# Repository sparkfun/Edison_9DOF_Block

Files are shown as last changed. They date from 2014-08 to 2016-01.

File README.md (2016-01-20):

SparkFun Edison 9 Degrees of Freedom
=====================

SparkFun Edison 9 Degrees of Freedom

[*SparkFun Edison 9 Degrees of Freedom (DEV-13033)*](https://www.sparkfun.com/products/13033)

The 9DOF board for the Edison uses the STMicro LSM9DS0 9 Degrees of Freedom IMU for full-range motion sensing. This chip combines a 3-axis accelerometer, a 3-axis gyroscope, and a 3-axis magnetometer. By default, the IMU is connected to the Edison through the I2C bus but can be configured to use the SPI bus.

Repository Contents
-------------------
 
* **/Hardware** - Eagle design files (.brd, .sch)
* **/Production** - Production panel files (.brd)

Documentation
--------------
* **[Hookup Guide](https://learn.sparkfun.com/tutorials/sparkfun-blocks-for-intel-edison---9-degrees-of-freedom-block-)** - Basic hookup guide for the Edison 9DOF.
* **[SparkFun Fritzing repo](https://github.com/sparkfun/Fritzing_Parts)** - Fritzing diagrams for SparkFun products.
* **[SparkFun 3D Model repo](https://github.com/sparkfun/3D_Models)** - 3D models of SparkFun products. 
* **[SparkFun Graphical Datasheets](https://github.com/sparkfun/Graphical_Datasheets)** -Graphical Datasheets for various SparkFun products.

License Information
-------------------

This product is _**open source**_! 

Please review the LICENSE.md file for license information. 

If you have any questions or concerns on licensing, please contact techsupport@sparkfun.com.

Distributed as-is; no warranty is given.

- Your friends at SparkFun.

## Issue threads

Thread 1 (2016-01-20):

Are the SDA and SCL pins exposed anywhere?

mikekberg, 2016-01-20:
I'm trying to debug some communications issues with this block. Is there anywhere I can get a probe onto the SDA or SCL pins for this board?

ShawnHymel, 2016-01-20:
SDA and SCL are the pads labeled "SDA" and "SCL" on the DATA and CLOCK 3-way solder jumpers. No real pins, but you can tack a couple of wires to the pads to connect to some probes.

Closed 2016-01-20.

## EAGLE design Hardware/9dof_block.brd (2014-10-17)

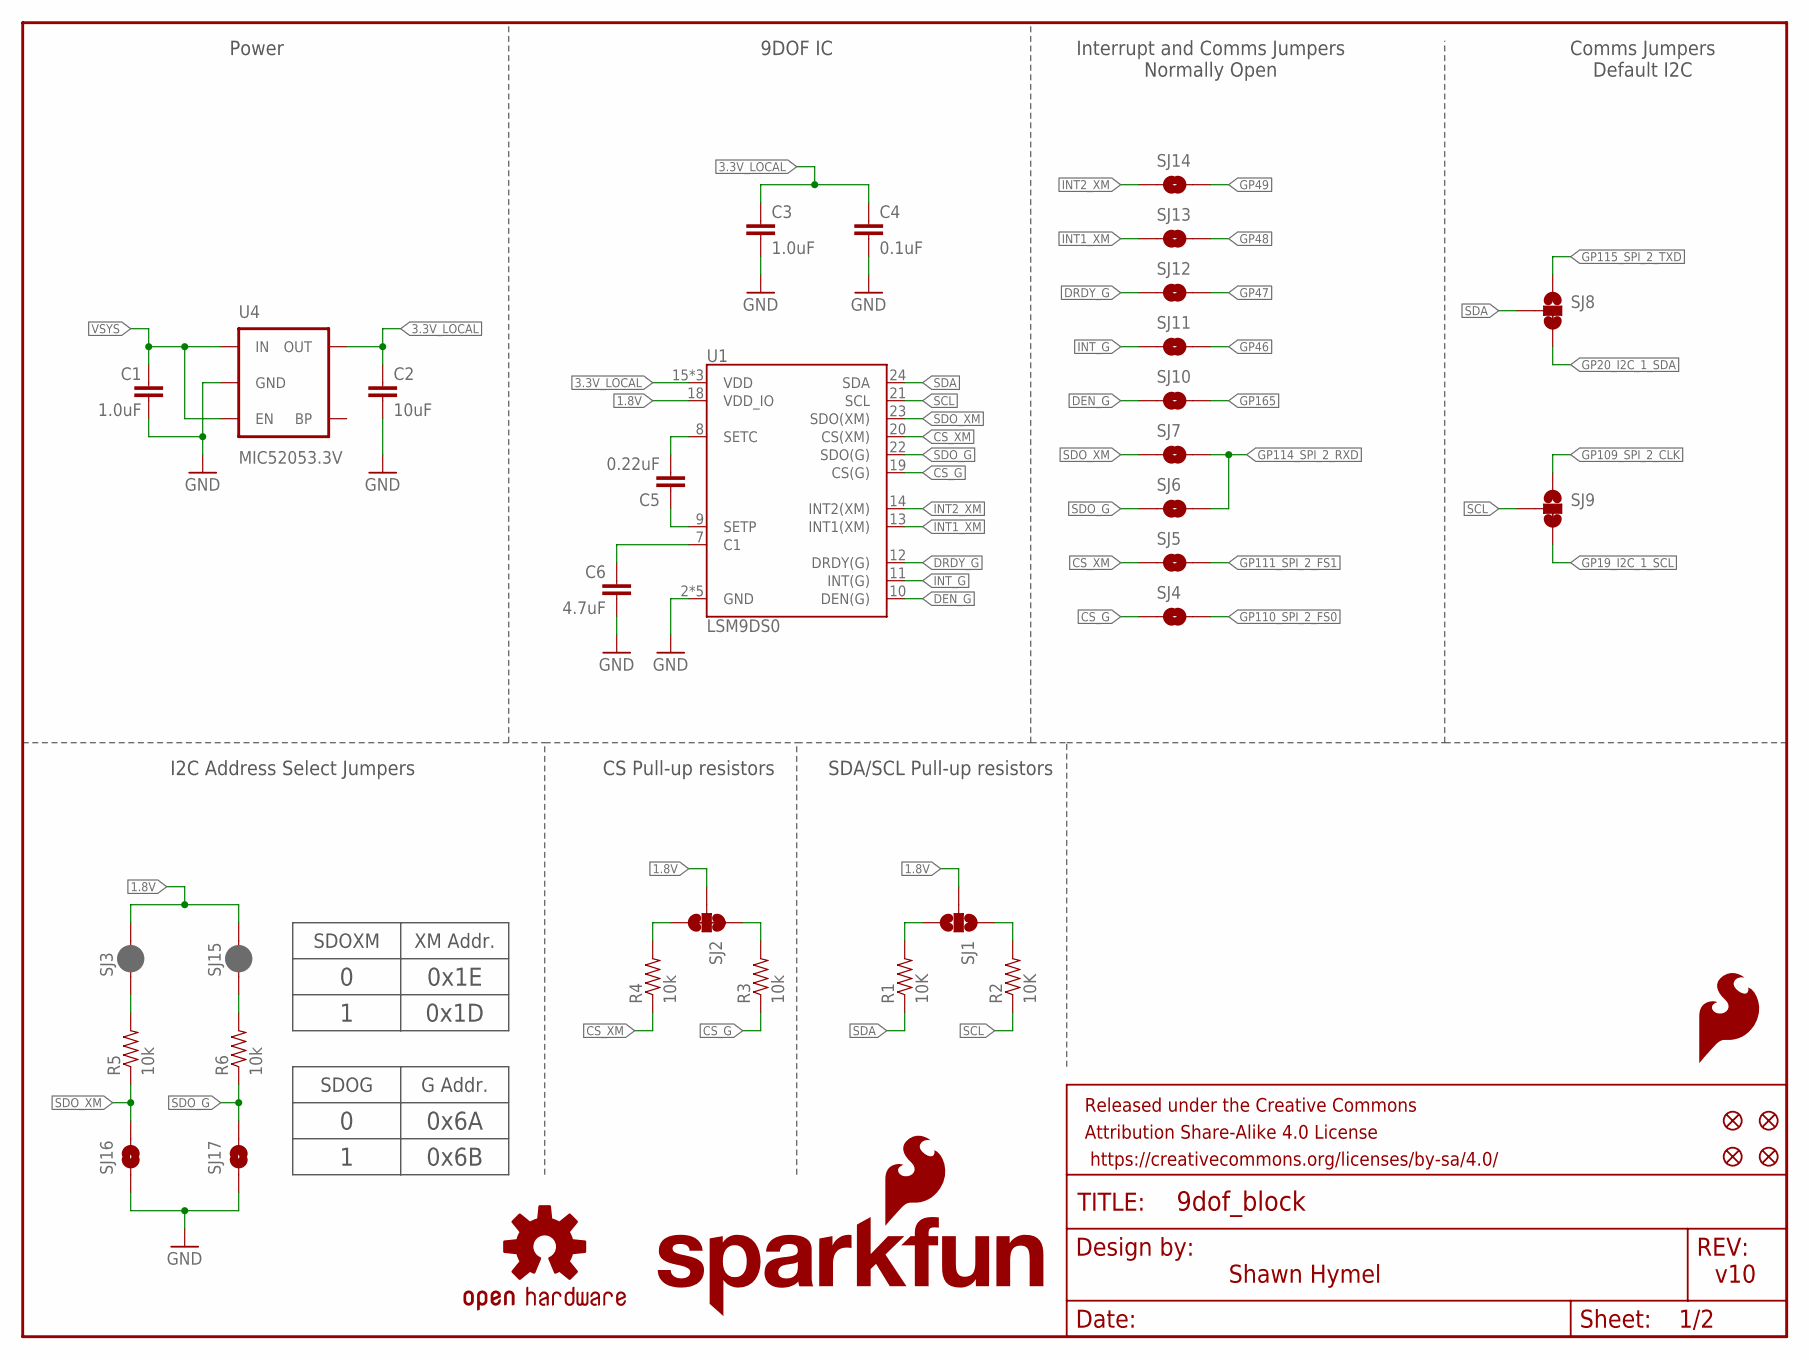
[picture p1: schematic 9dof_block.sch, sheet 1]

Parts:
C1, C3: 1.0uF; 0603-CAP
C2: 10uF; 0805
C4: 0.1uF; 0603-CAP
C5: 0.22uF; 0603-CAP
C6: 4.7uF; 0603-CAP
FID1, FID2, FID3, FID4: FIDUCIAL1X2; FIDUCIAL-1X2
FRAME1: FRAME-LETTER; CREATIVE_COMMONS
LOGO1: SFE_LOGO_FLAME.2_INCH; SFE_LOGO_FLAME_.2
LOGO2: OSHW-LOGOS; OSHW-LOGO-S
LOGO3: SFE_LOGO_NAME_FLAME.1_INCH; SFE_LOGO_NAME_FLAME_.1
R1, R2: 10K; 0603-RES
R3, R4, R5, R6: 10k; 0603-RES
SJ1: JUMPER-PAD-3-NOYES_SILK; PAD-JUMPER-3-NO_YES_SILK
SJ2: JUMPER-PAD-3-NC_BY_TRACE; PAD-JUMPER-3-3OF3_NC_BY_TRACE_YES_SILK_FULL_BOX
SJ3, SJ15: JUMPER-PAD-2-NC_BY_PASTE; PAD-JUMPER-2-NC_BY_PASTE_YES_SILK
SJ4, SJ5, SJ6, SJ7, SJ10, SJ11, SJ12, SJ13, SJ14, SJ16, SJ17: JUMPER-PAD-2-NOYES_SILK; PAD-JUMPER-2-NO_YES_SILK
SJ8, SJ9: JUMPER-PAD-3-2OF3_NC_BY_TRACE_SMALL; PAD-JUMPER-3-2OF3_NC_BY_TRACE_YES_SILK_FULL_BOX
U1: LSM9DS0; LGA-24
U4: MIC52053.3V; SOT23-5

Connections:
1.8V: SJ1.2, SJ2.2, SJ3.2, SJ15.2, U1.18 (VDD_IO); also elsewhere on the board
3.3V_LOCAL: C2.1, C3.1, C4.1, U1.15 (VDD), U1.16 (VDD), U1.17 (VDD), U4.5 (OUT)
CS_G: R3.1, SJ4.1, U1.19 (CS(G))
CS_XM: R4.1, SJ5.1, U1.20 (CS(XM))
DEN_G: SJ10.1, U1.10 (DEN(G))
DRDY_G: SJ12.1, U1.12 (DRDY(G))
GND: C1.2, C2.2, C3.2, C4.2, C6.2, SJ16.1, SJ17.1, U1.2 (GND), U1.3 (GND), U1.4 (GND), U1.5 (GND), U1.6 (GND), U4.2 (GND); also elsewhere on the board
GP19_I2C_1_SCL: SJ9.3; also elsewhere on the board
GP20_I2C_1_SDA: SJ8.3; also elsewhere on the board
GP46: SJ11.2; also elsewhere on the board
GP47: SJ12.2; also elsewhere on the board
GP48: SJ13.2; also elsewhere on the board
GP49: SJ14.2; also elsewhere on the board
GP109_SPI_2_CLK: SJ9.1; also elsewhere on the board
GP110_SPI_2_FS0: SJ4.2; also elsewhere on the board
GP111_SPI_2_FS1: SJ5.2; also elsewhere on the board
GP114_SPI_2_RXD: SJ6.2, SJ7.2; also elsewhere on the board
GP115_SPI_2_TXD: SJ8.1; also elsewhere on the board
GP165: SJ10.2; also elsewhere on the board
INT1_XM: SJ13.1, U1.13 (INT1(XM))
INT2_XM: SJ14.1, U1.14 (INT2(XM))
INT_G: SJ11.1, U1.11 (INT(G))
unnamed: C5.1, U1.9 (SETP)
unnamed: C5.2, U1.8 (SETC)
unnamed: C6.1, U1.7 (C1)
unnamed: R3.2, SJ2.1
unnamed: R4.2, SJ2.3
unnamed: R1.2, SJ1.3
unnamed: R2.2, SJ1.1
unnamed: R5.2, SJ3.1
unnamed: R6.2, SJ15.1
SCL: R2.1, SJ9.2, U1.21 (SCL)
SDA: R1.1, SJ8.2, U1.24 (SDA)
SDO_G: R6.1, SJ6.1, SJ17.2, U1.22 (SDO(G))
SDO_XM: R5.1, SJ7.1, SJ16.2, U1.23 (SDO(XM))
VSYS: C1.1, U4.1 (IN), U4.3 (EN); also elsewhere on the board

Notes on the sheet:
I2C Address Select Jumpers
SDA/SCL Pull-up resistors
9DOF IC
Interrupt and Comms Jumpers Normally Open
Comms Jumpers Default I2C
Power
CS Pull-up resistors
SDOXM
XM Addr.
0x1E
0x1D
SDOG
G Addr.
0x6A
0x6B
v10
Shawn Hymel

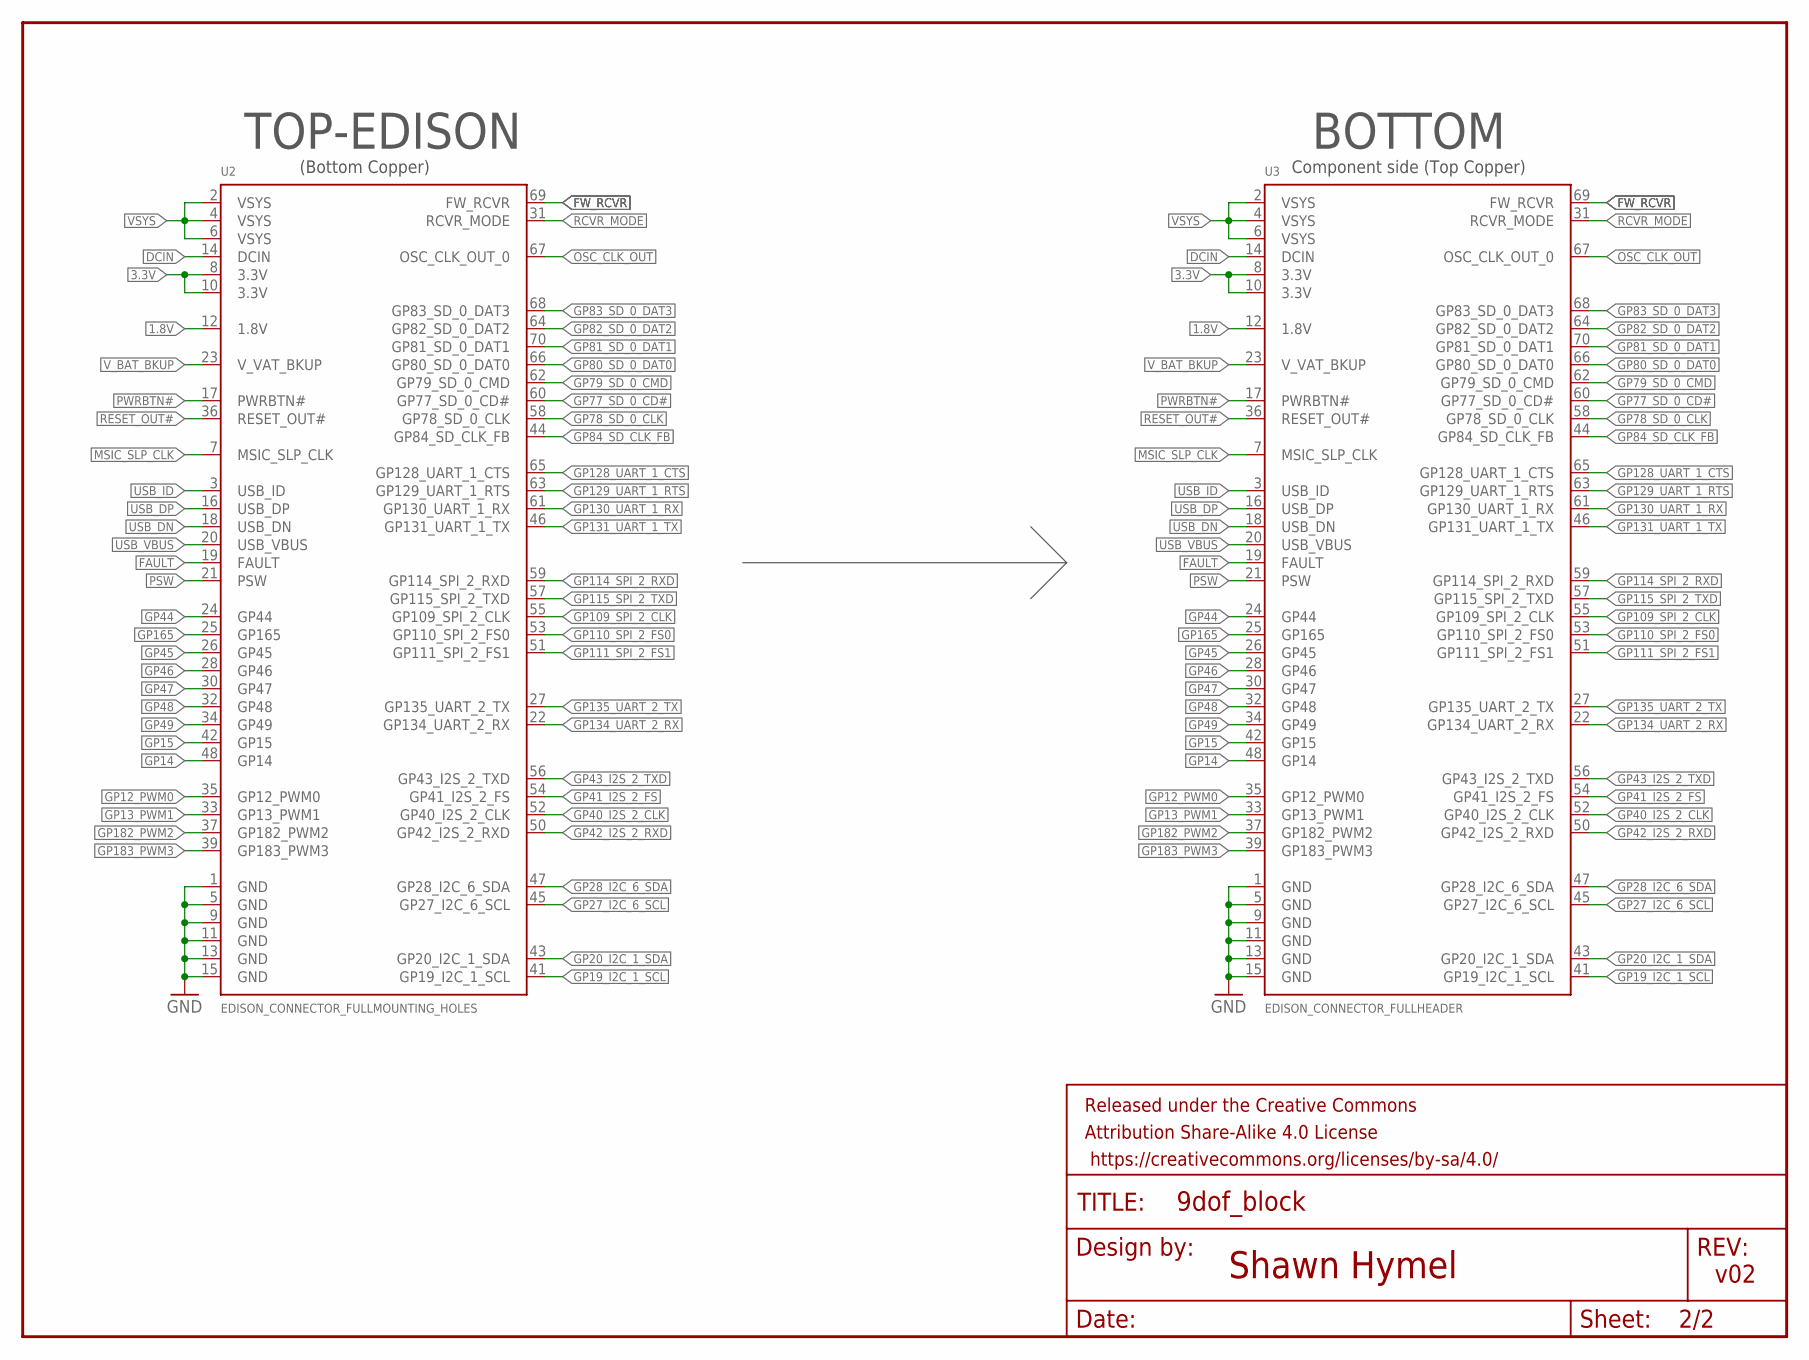
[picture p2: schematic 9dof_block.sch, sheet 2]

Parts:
FRAME2: FRAME-LETTER; CREATIVE_COMMONS
U2: EDISON_CONNECTOR_FULLMOUNTING_HOLES; EDISON_DAUGHTER
U3: EDISON_CONNECTOR_FULLHEADER; DF40C-70DP-0.4(51)

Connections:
1.8V: U2.12 (1.8V), U3.12 (1.8V); also elsewhere on the board
3.3V: U2.8 (3.3V), U2.10 (3.3V), U3.8 (3.3V), U3.10 (3.3V)
DCIN: U2.14 (DCIN), U3.14 (DCIN)
FAULT: U2.19 (FAULT), U3.19 (FAULT)
FW_RCVR: U2.69 (FW_RCVR), U3.69 (FW_RCVR)
GND: U2.1 (GND), U2.5 (GND), U2.9 (GND), U2.11 (GND), U2.13 (GND), U2.15 (GND), U3.1 (GND), U3.5 (GND), U3.9 (GND), U3.11 (GND), U3.13 (GND), U3.15 (GND); also elsewhere on the board
GP12_PWM0: U2.35 (GP12_PWM0), U3.35 (GP12_PWM0)
GP13_PWM1: U2.33 (GP13_PWM1), U3.33 (GP13_PWM1)
GP14: U2.48 (GP14), U3.48 (GP14)
GP15: U2.42 (GP15), U3.42 (GP15)
GP19_I2C_1_SCL: U2.41 (GP19_I2C_1_SCL), U3.41 (GP19_I2C_1_SCL); also elsewhere on the board
GP20_I2C_1_SDA: U2.43 (GP20_I2C_1_SDA), U3.43 (GP20_I2C_1_SDA); also elsewhere on the board
GP27_I2C_6_SCL: U2.45 (GP27_I2C_6_SCL), U3.45 (GP27_I2C_6_SCL)
GP28_I2C_6_SDA: U2.47 (GP28_I2C_6_SDA), U3.47 (GP28_I2C_6_SDA)
GP40_I2S_2_CLK: U2.52 (GP40_I2S_2_CLK), U3.52 (GP40_I2S_2_CLK)
GP41_I2S_2_FS: U2.54 (GP41_I2S_2_FS), U3.54 (GP41_I2S_2_FS)
GP42_I2S_2_RXD: U2.50 (GP42_I2S_2_RXD), U3.50 (GP42_I2S_2_RXD)
GP43_I2S_2_TXD: U2.56 (GP43_I2S_2_TXD), U3.56 (GP43_I2S_2_TXD)
GP44: U2.24 (GP44), U3.24 (GP44)
GP45: U2.26 (GP45), U3.26 (GP45)
GP46: U2.28 (GP46), U3.28 (GP46); also elsewhere on the board
GP47: U2.30 (GP47), U3.30 (GP47); also elsewhere on the board
GP48: U2.32 (GP48), U3.32 (GP48); also elsewhere on the board
GP49: U2.34 (GP49), U3.34 (GP49); also elsewhere on the board
GP77_SD_0_CD#: U2.60 (GP77_SD_0_CD#), U3.60 (GP77_SD_0_CD#)
GP78_SD_0_CLK: U2.58 (GP78_SD_0_CLK), U3.58 (GP78_SD_0_CLK)
GP79_SD_0_CMD: U2.62 (GP79_SD_0_CMD), U3.62 (GP79_SD_0_CMD)
GP80_SD_0_DAT0: U2.66 (GP80_SD_0_DAT0), U3.66 (GP80_SD_0_DAT0)
GP81_SD_0_DAT1: U2.70 (GP81_SD_0_DAT1), U3.70 (GP81_SD_0_DAT1)
GP82_SD_0_DAT2: U2.64 (GP82_SD_0_DAT2), U3.64 (GP82_SD_0_DAT2)
GP83_SD_0_DAT3: U2.68 (GP83_SD_0_DAT3), U3.68 (GP83_SD_0_DAT3)
GP84_SD_CLK_FB: U2.44 (GP84_SD_CLK_FB), U3.44 (GP84_SD_CLK_FB)
GP109_SPI_2_CLK: U2.55 (GP109_SPI_2_CLK), U3.55 (GP109_SPI_2_CLK); also elsewhere on the board
GP110_SPI_2_FS0: U2.53 (GP110_SPI_2_FS0), U3.53 (GP110_SPI_2_FS0); also elsewhere on the board
GP111_SPI_2_FS1: U2.51 (GP111_SPI_2_FS1), U3.51 (GP111_SPI_2_FS1); also elsewhere on the board
GP114_SPI_2_RXD: U2.59 (GP114_SPI_2_RXD), U3.59 (GP114_SPI_2_RXD); also elsewhere on the board
GP115_SPI_2_TXD: U2.57 (GP115_SPI_2_TXD), U3.57 (GP115_SPI_2_TXD); also elsewhere on the board
GP128_UART_1_CTS: U2.65 (GP128_UART_1_CTS), U3.65 (GP128_UART_1_CTS)
GP129_UART_1_RTS: U2.63 (GP129_UART_1_RTS), U3.63 (GP129_UART_1_RTS)
GP130_UART_1_RX: U2.61 (GP130_UART_1_RX), U3.61 (GP130_UART_1_RX)
GP131_UART_1_TX: U2.46 (GP131_UART_1_TX), U3.46 (GP131_UART_1_TX)
GP134_UART_2_RX: U2.22 (GP134_UART_2_RX), U3.22 (GP134_UART_2_RX)
GP135_UART_2_TX: U2.27 (GP135_UART_2_TX), U3.27 (GP135_UART_2_TX)
GP165: U2.25 (GP165), U3.25 (GP165); also elsewhere on the board
GP182_PWM2: U2.37 (GP182_PWM2), U3.37 (GP182_PWM2)
GP183_PWM3: U2.39 (GP183_PWM3), U3.39 (GP183_PWM3)
MSIC_SLP_CLK: U2.7 (MSIC_SLP_CLK), U3.7 (MSIC_SLP_CLK)
OSC_CLK_OUT: U2.67 (OSC_CLK_OUT_0), U3.67 (OSC_CLK_OUT_0)
PSW: U2.21 (PSW), U3.21 (PSW)
PWRBTN#: U2.17 (PWRBTN#), U3.17 (PWRBTN#)
RCVR_MODE: U2.31 (RCVR_MODE), U3.31 (RCVR_MODE)
RESET_OUT#: U2.36 (RESET_OUT#), U3.36 (RESET_OUT#)
USB_DN: U2.18 (USB_DN), U3.18 (USB_DN)
USB_DP: U2.16 (USB_DP), U3.16 (USB_DP)
USB_ID: U2.3 (USB_ID), U3.3 (USB_ID)
USB_VBUS: U2.20 (USB_VBUS), U3.20 (USB_VBUS)
VSYS: U2.2 (VSYS), U2.4 (VSYS), U2.6 (VSYS), U3.2 (VSYS), U3.4 (VSYS), U3.6 (VSYS); also elsewhere on the board
V_BAT_BKUP: U2.23 (V_VAT_BKUP), U3.23 (V_VAT_BKUP)

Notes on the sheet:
TOP-EDISON
BOTTOM
Component side (Top Copper)
(Bottom Copper)
Shawn Hymel
v02

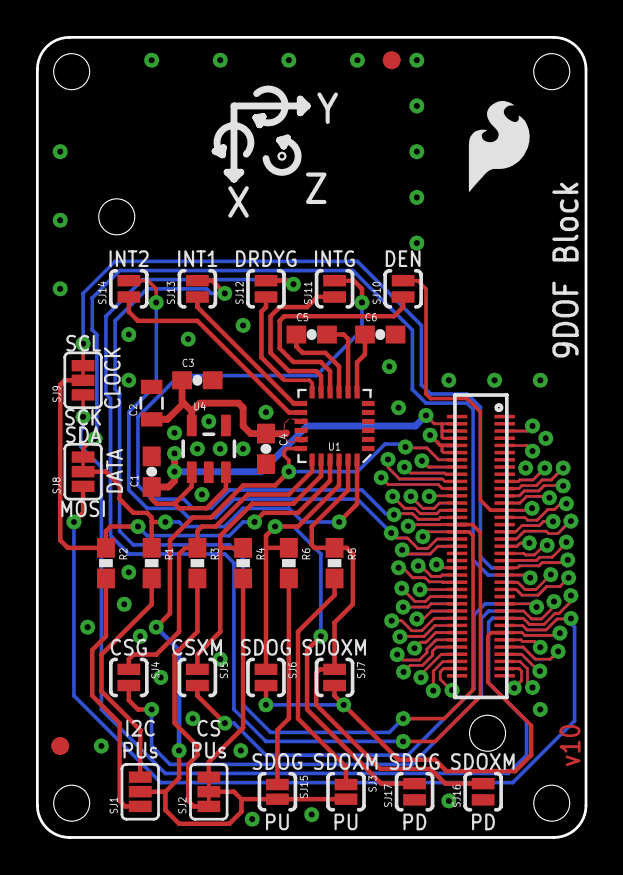
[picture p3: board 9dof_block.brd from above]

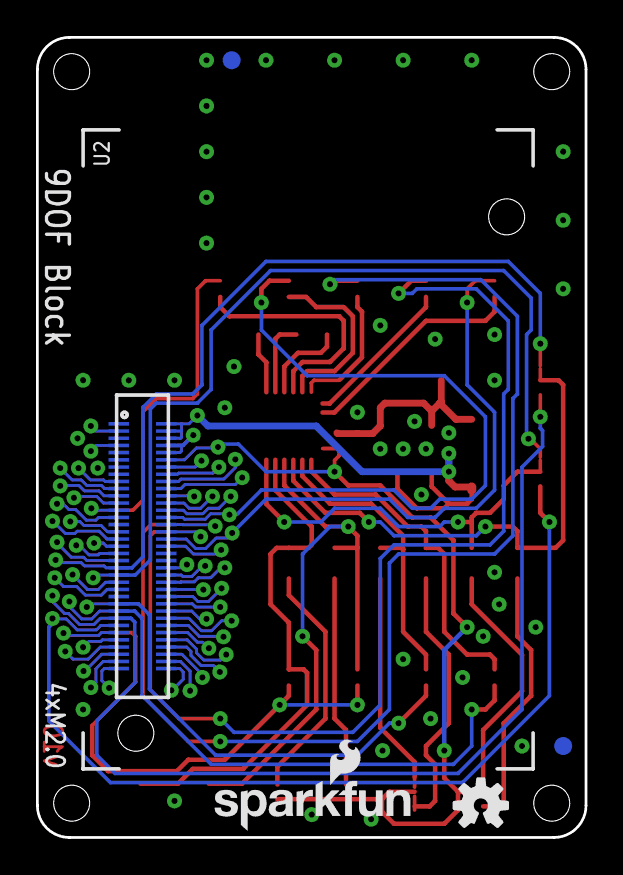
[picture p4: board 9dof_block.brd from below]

Board: 2 copper layers, 30.5 x 44.5 mm, 42 parts (6 on the bottom side), 79 nets.

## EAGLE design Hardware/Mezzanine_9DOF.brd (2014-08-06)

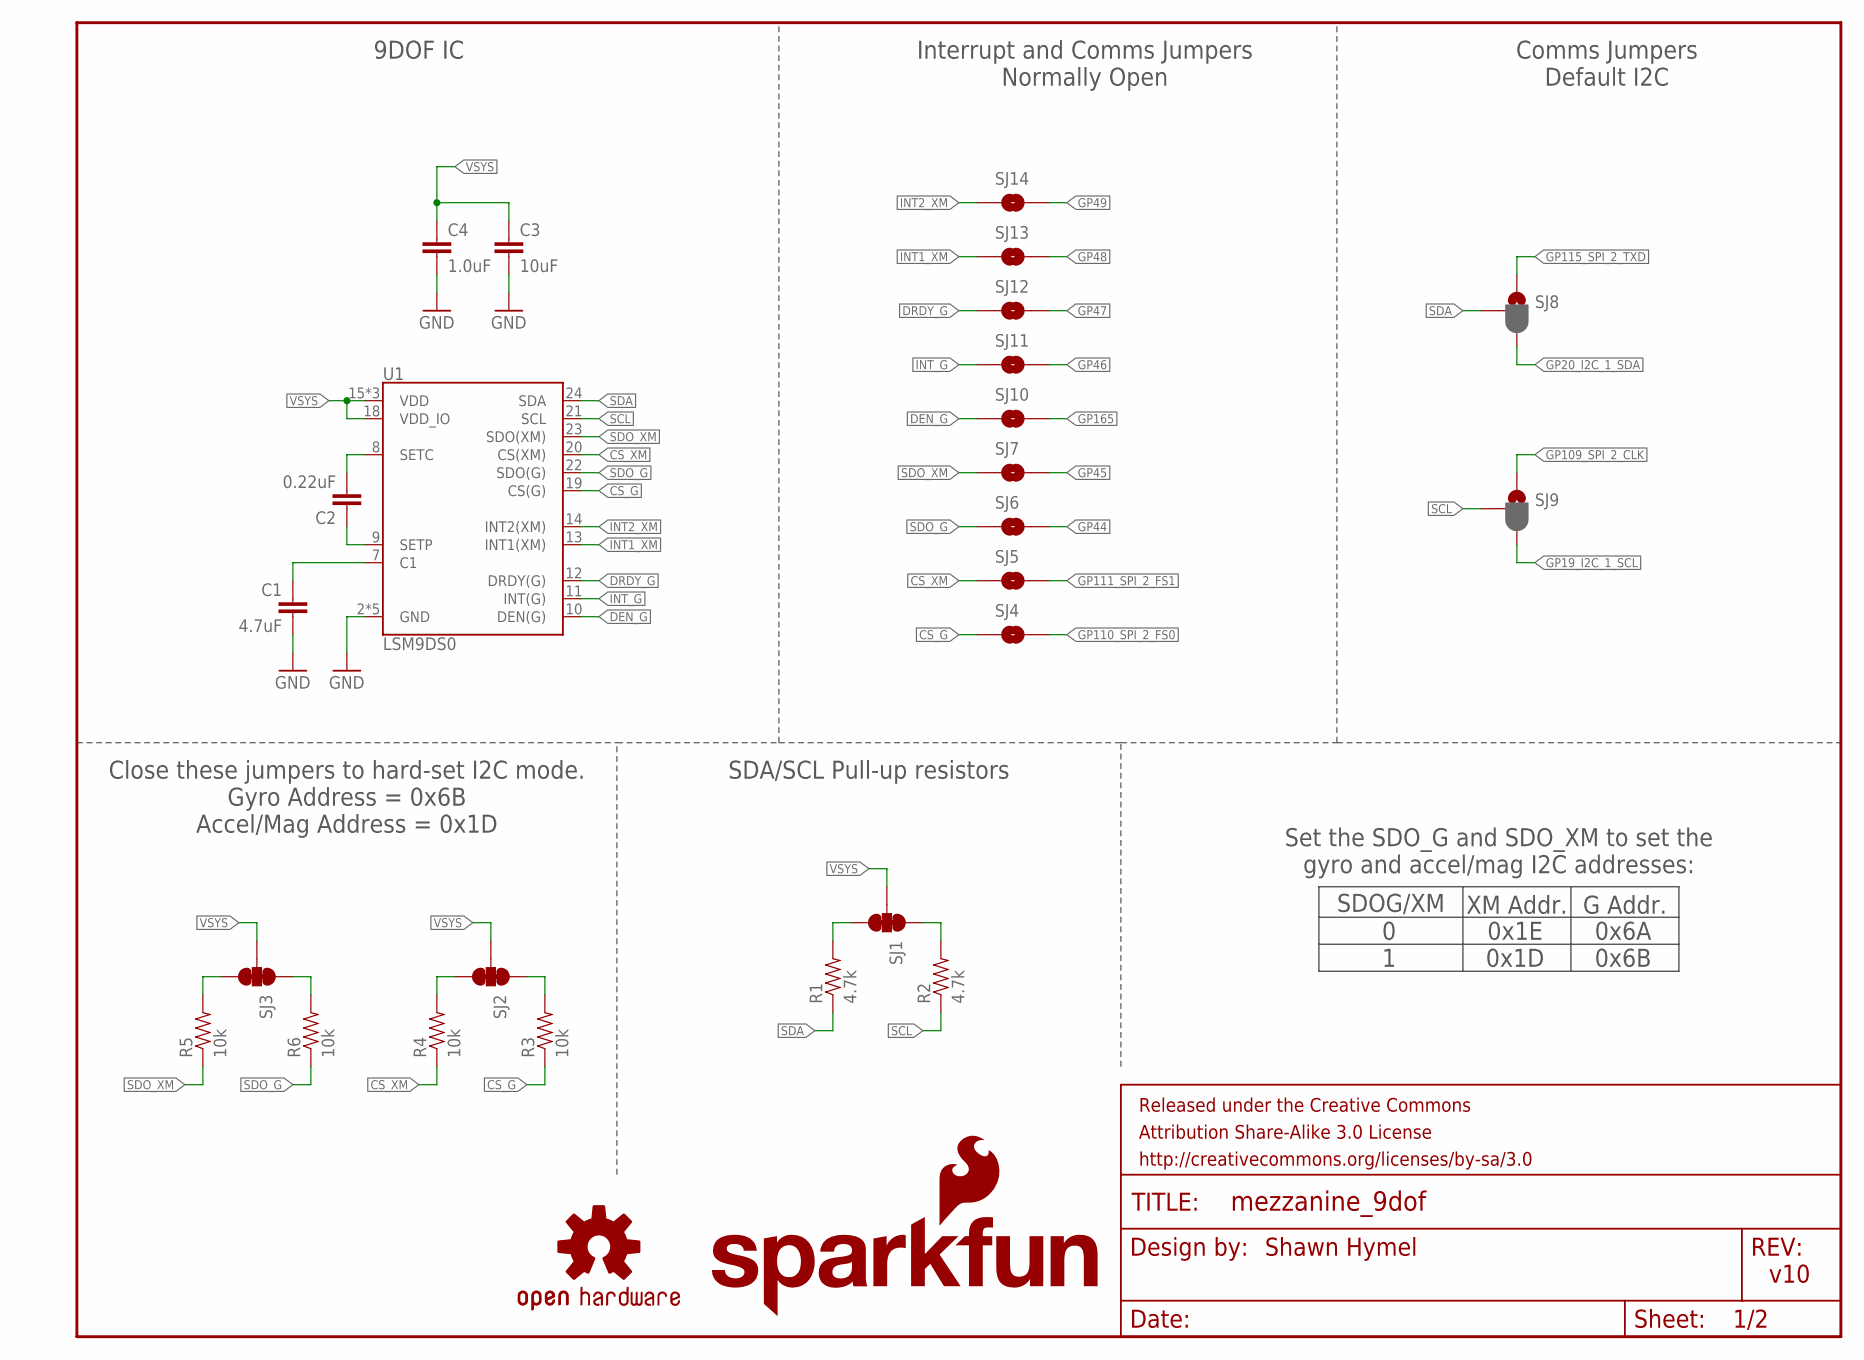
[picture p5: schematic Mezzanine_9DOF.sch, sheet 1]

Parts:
C1: 4.7uF; 0603-CAP
C2: 0.22uF; 0603-CAP
C3: 10uF; 0805
C4: 1.0uF; 0603-CAP
FRAME1: FRAME-LETTER; CREATIVE_COMMONS
LOGO2: OSHW-LOGOS; OSHW-LOGO-S
LOGO3: SFE_LOGO_NAME_FLAME.1_INCH; SFE_LOGO_NAME_FLAME_.1
R1, R2: 4.7k; 0603-RES
R3, R4, R5, R6: 10k; 0603-RES
SJ1, SJ2, SJ3: SOLDERJUMPER_2WAYS; SJ_3
SJ4, SJ5, SJ6, SJ7, SJ10, SJ11, SJ12, SJ13, SJ14: JUMPER-PAD-2-NOYES_SILK; PAD-JUMPER-2-NO_YES_SILK
SJ8, SJ9: JUMPER-PAD-3-2OF3_NC_BY_PASTE; PAD-JUMPER-3-2OF3_NC_BY_PASTE_YES_SILK_FULL_BOX
U1: LSM9DS0; LGA-24

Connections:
CS_G: R3.1, SJ4.1, U1.19 (CS(G))
CS_XM: R4.1, SJ5.1, U1.20 (CS(XM))
DEN_G: SJ10.1, U1.10 (DEN(G))
DRDY_G: SJ12.1, U1.12 (DRDY(G))
GND: C1.2, C3.2, C4.2, U1.2 (GND), U1.3 (GND), U1.4 (GND), U1.5 (GND), U1.6 (GND); also elsewhere on the board
GP19_I2C_1_SCL: SJ9.3; also elsewhere on the board
GP20_I2C_1_SDA: SJ8.3; also elsewhere on the board
GP44: SJ6.2; also elsewhere on the board
GP45: SJ7.2; also elsewhere on the board
GP46: SJ11.2; also elsewhere on the board
GP47: SJ12.2; also elsewhere on the board
GP48: SJ13.2; also elsewhere on the board
GP49: SJ14.2; also elsewhere on the board
GP109_SPI_2_CLK: SJ9.1; also elsewhere on the board
GP110_SPI_2_FS0: SJ4.2; also elsewhere on the board
GP111_SPI_2_FS1: SJ5.2; also elsewhere on the board
GP115_SPI_2_TXD: SJ8.1; also elsewhere on the board
GP165: SJ10.2; also elsewhere on the board
INT1_XM: SJ13.1, U1.13 (INT1(XM))
INT2_XM: SJ14.1, U1.14 (INT2(XM))
INT_G: SJ11.1, U1.11 (INT(G))
unnamed: C2.1, U1.9 (SETP)
unnamed: C2.2, U1.8 (SETC)
unnamed: C1.1, U1.7 (C1)
unnamed: R3.2, SJ2.1
unnamed: R4.2, SJ2.3
unnamed: R1.2, SJ1.3
unnamed: R2.2, SJ1.1
unnamed: R5.2, SJ3.3
unnamed: R6.2, SJ3.1
SCL: R2.1, SJ9.2, U1.21 (SCL)
SDA: R1.1, SJ8.2, U1.24 (SDA)
SDO_G: R6.1, SJ6.1, U1.22 (SDO(G))
SDO_XM: R5.1, SJ7.1, U1.23 (SDO(XM))
VSYS: C3.1, C4.1, SJ1.2, SJ2.2, SJ3.2, U1.15 (VDD), U1.16 (VDD), U1.17 (VDD), U1.18 (VDD_IO); also elsewhere on the board

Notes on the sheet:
Close these jumpers to hard-set I2C mode. Gyro Address = 0x6B Accel/Mag Address = 0x1D
SDA/SCL Pull-up resistors
SDOG/XM
0x1E 0x1D
XM Addr.
0 1
G Addr.
0x6A 0x6B
Set the SDO_G and SDO_XM to set the gyro and accel/mag I2C addresses:
Shawn Hymel
v10
9DOF IC
Interrupt and Comms Jumpers Normally Open
Comms Jumpers Default I2C

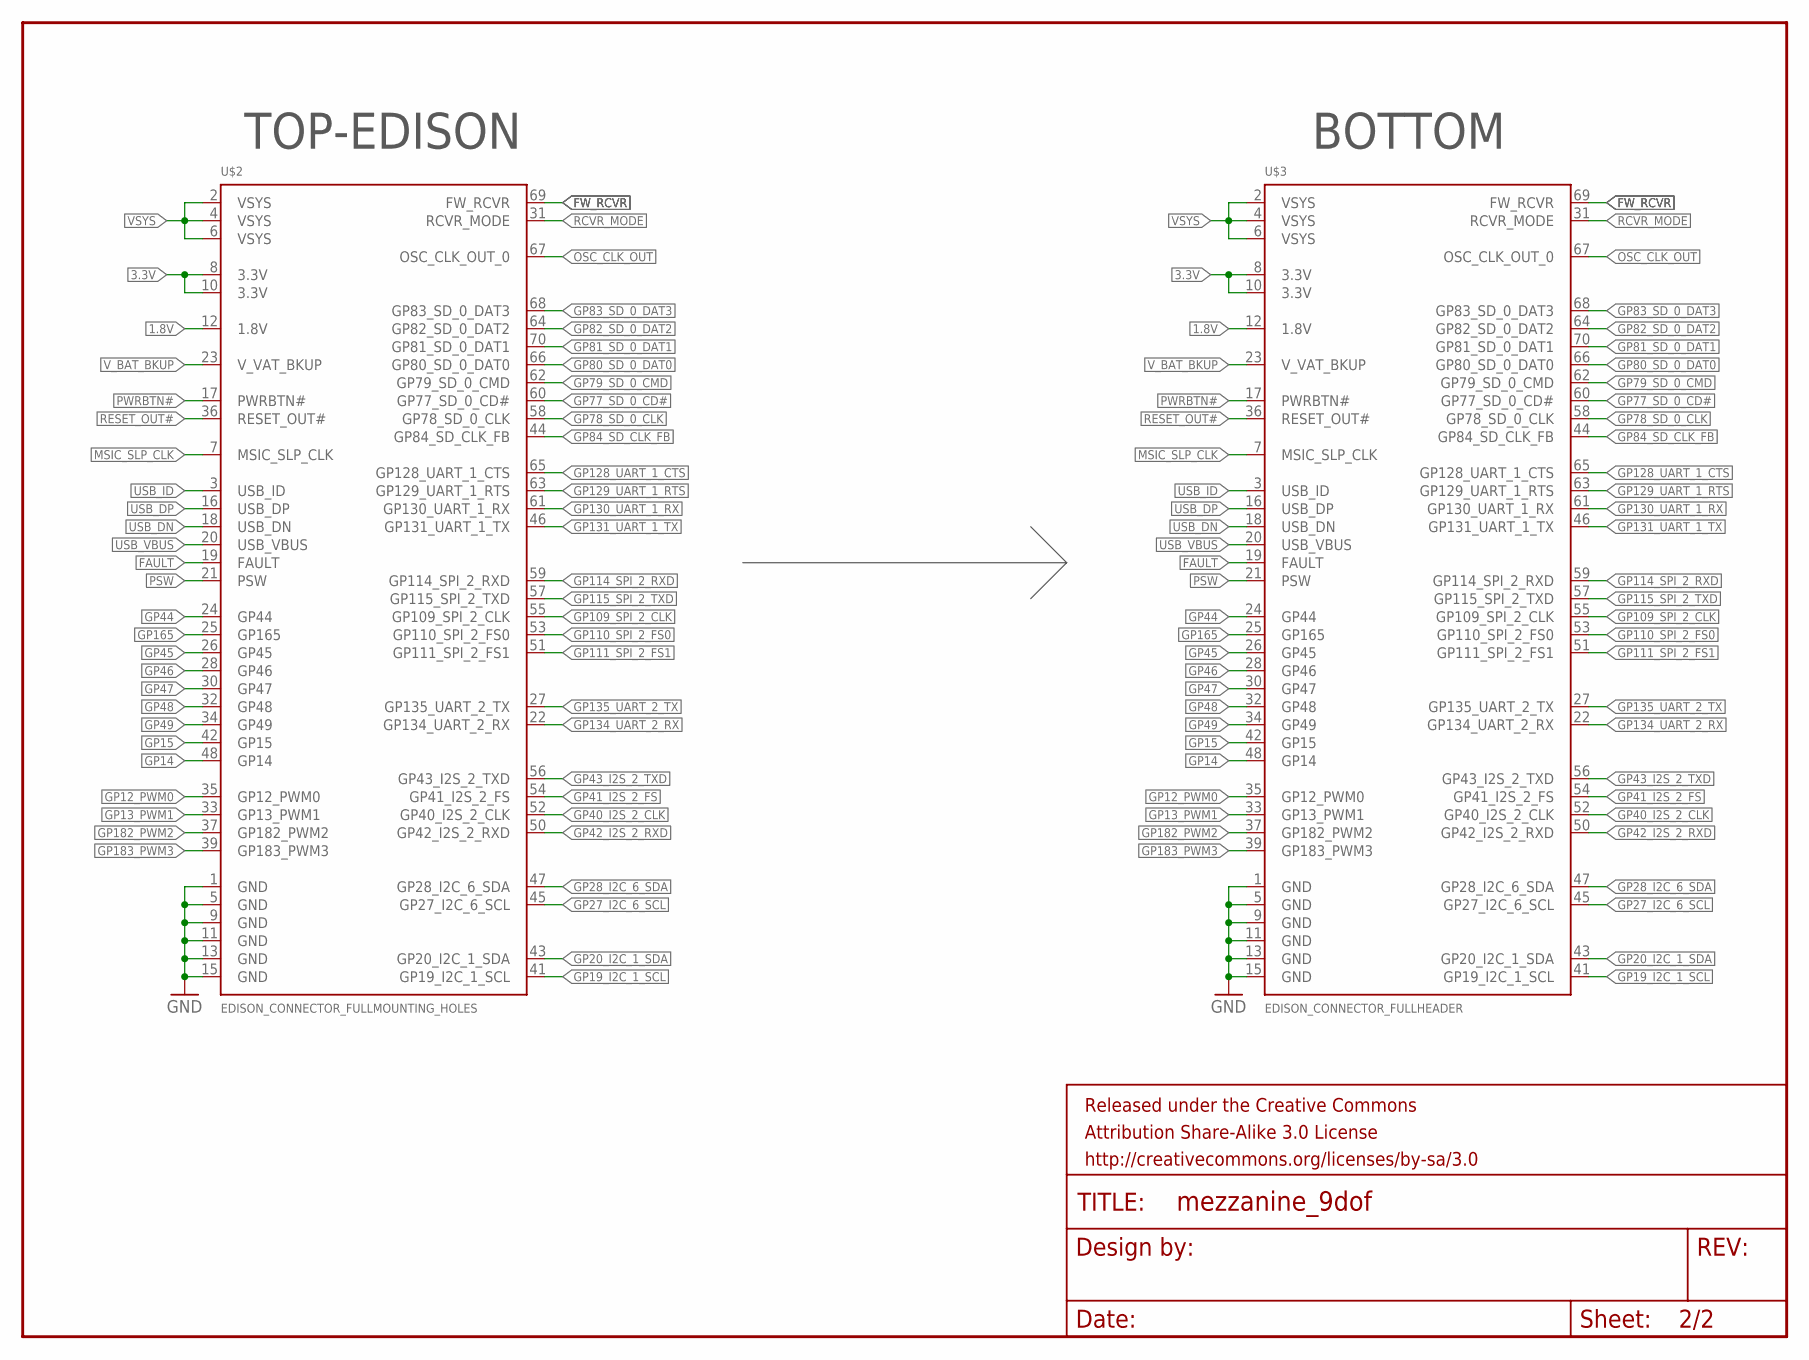
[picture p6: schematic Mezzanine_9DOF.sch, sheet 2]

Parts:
FRAME2: FRAME-LETTER; CREATIVE_COMMONS
U$2: EDISON_CONNECTOR_FULLMOUNTING_HOLES; EDISON_DAUGHTER
U$3: EDISON_CONNECTOR_FULLHEADER; DF40C-70DP-0.4(51)

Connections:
1.8V: U$2.12 (1.8V), U$3.12 (1.8V)
3.3V: U$2.8 (3.3V), U$2.10 (3.3V), U$3.8 (3.3V), U$3.10 (3.3V)
FAULT: U$2.19 (FAULT), U$3.19 (FAULT)
FW_RCVR: U$2.69 (FW_RCVR), U$3.69 (FW_RCVR)
GND: U$2.1 (GND), U$2.5 (GND), U$2.9 (GND), U$2.11 (GND), U$2.13 (GND), U$2.15 (GND), U$3.1 (GND), U$3.5 (GND), U$3.9 (GND), U$3.11 (GND), U$3.13 (GND), U$3.15 (GND); also elsewhere on the board
GP12_PWM0: U$2.35 (GP12_PWM0), U$3.35 (GP12_PWM0)
GP13_PWM1: U$2.33 (GP13_PWM1), U$3.33 (GP13_PWM1)
GP14: U$2.48 (GP14), U$3.48 (GP14)
GP15: U$2.42 (GP15), U$3.42 (GP15)
GP19_I2C_1_SCL: U$2.41 (GP19_I2C_1_SCL), U$3.41 (GP19_I2C_1_SCL); also elsewhere on the board
GP20_I2C_1_SDA: U$2.43 (GP20_I2C_1_SDA), U$3.43 (GP20_I2C_1_SDA); also elsewhere on the board
GP27_I2C_6_SCL: U$2.45 (GP27_I2C_6_SCL), U$3.45 (GP27_I2C_6_SCL)
GP28_I2C_6_SDA: U$2.47 (GP28_I2C_6_SDA), U$3.47 (GP28_I2C_6_SDA)
GP40_I2S_2_CLK: U$2.52 (GP40_I2S_2_CLK), U$3.52 (GP40_I2S_2_CLK)
GP41_I2S_2_FS: U$2.54 (GP41_I2S_2_FS), U$3.54 (GP41_I2S_2_FS)
GP42_I2S_2_RXD: U$2.50 (GP42_I2S_2_RXD), U$3.50 (GP42_I2S_2_RXD)
GP43_I2S_2_TXD: U$2.56 (GP43_I2S_2_TXD), U$3.56 (GP43_I2S_2_TXD)
GP44: U$2.24 (GP44), U$3.24 (GP44); also elsewhere on the board
GP45: U$2.26 (GP45), U$3.26 (GP45); also elsewhere on the board
GP46: U$2.28 (GP46), U$3.28 (GP46); also elsewhere on the board
GP47: U$2.30 (GP47), U$3.30 (GP47); also elsewhere on the board
GP48: U$2.32 (GP48), U$3.32 (GP48); also elsewhere on the board
GP49: U$2.34 (GP49), U$3.34 (GP49); also elsewhere on the board
GP77_SD_0_CD#: U$2.60 (GP77_SD_0_CD#), U$3.60 (GP77_SD_0_CD#)
GP78_SD_0_CLK: U$2.58 (GP78_SD_0_CLK), U$3.58 (GP78_SD_0_CLK)
GP79_SD_0_CMD: U$2.62 (GP79_SD_0_CMD), U$3.62 (GP79_SD_0_CMD)
GP80_SD_0_DAT0: U$2.66 (GP80_SD_0_DAT0), U$3.66 (GP80_SD_0_DAT0)
GP81_SD_0_DAT1: U$2.70 (GP81_SD_0_DAT1), U$3.70 (GP81_SD_0_DAT1)
GP82_SD_0_DAT2: U$2.64 (GP82_SD_0_DAT2), U$3.64 (GP82_SD_0_DAT2)
GP83_SD_0_DAT3: U$2.68 (GP83_SD_0_DAT3), U$3.68 (GP83_SD_0_DAT3)
GP84_SD_CLK_FB: U$2.44 (GP84_SD_CLK_FB), U$3.44 (GP84_SD_CLK_FB)
GP109_SPI_2_CLK: U$2.55 (GP109_SPI_2_CLK), U$3.55 (GP109_SPI_2_CLK); also elsewhere on the board
GP110_SPI_2_FS0: U$2.53 (GP110_SPI_2_FS0), U$3.53 (GP110_SPI_2_FS0); also elsewhere on the board
GP111_SPI_2_FS1: U$2.51 (GP111_SPI_2_FS1), U$3.51 (GP111_SPI_2_FS1); also elsewhere on the board
GP114_SPI_2_RXD: U$2.59 (GP114_SPI_2_RXD), U$3.59 (GP114_SPI_2_RXD)
GP115_SPI_2_TXD: U$2.57 (GP115_SPI_2_TXD), U$3.57 (GP115_SPI_2_TXD); also elsewhere on the board
GP128_UART_1_CTS: U$2.65 (GP128_UART_1_CTS), U$3.65 (GP128_UART_1_CTS)
GP129_UART_1_RTS: U$2.63 (GP129_UART_1_RTS), U$3.63 (GP129_UART_1_RTS)
GP130_UART_1_RX: U$2.61 (GP130_UART_1_RX), U$3.61 (GP130_UART_1_RX)
GP131_UART_1_TX: U$2.46 (GP131_UART_1_TX), U$3.46 (GP131_UART_1_TX)
GP134_UART_2_RX: U$2.22 (GP134_UART_2_RX), U$3.22 (GP134_UART_2_RX)
GP135_UART_2_TX: U$2.27 (GP135_UART_2_TX), U$3.27 (GP135_UART_2_TX)
GP165: U$2.25 (GP165), U$3.25 (GP165); also elsewhere on the board
GP182_PWM2: U$2.37 (GP182_PWM2), U$3.37 (GP182_PWM2)
GP183_PWM3: U$2.39 (GP183_PWM3), U$3.39 (GP183_PWM3)
MSIC_SLP_CLK: U$2.7 (MSIC_SLP_CLK), U$3.7 (MSIC_SLP_CLK)
OSC_CLK_OUT: U$2.67 (OSC_CLK_OUT_0), U$3.67 (OSC_CLK_OUT_0)
PSW: U$2.21 (PSW), U$3.21 (PSW)
PWRBTN#: U$2.17 (PWRBTN#), U$3.17 (PWRBTN#)
RCVR_MODE: U$2.31 (RCVR_MODE), U$3.31 (RCVR_MODE)
RESET_OUT#: U$2.36 (RESET_OUT#), U$3.36 (RESET_OUT#)
USB_DN: U$2.18 (USB_DN), U$3.18 (USB_DN)
USB_DP: U$2.16 (USB_DP), U$3.16 (USB_DP)
USB_ID: U$2.3 (USB_ID), U$3.3 (USB_ID)
USB_VBUS: U$2.20 (USB_VBUS), U$3.20 (USB_VBUS)
VSYS: U$2.2 (VSYS), U$2.4 (VSYS), U$2.6 (VSYS), U$3.2 (VSYS), U$3.4 (VSYS), U$3.6 (VSYS); also elsewhere on the board
V_BAT_BKUP: U$2.23 (V_VAT_BKUP), U$3.23 (V_VAT_BKUP)

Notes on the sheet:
TOP-EDISON
BOTTOM

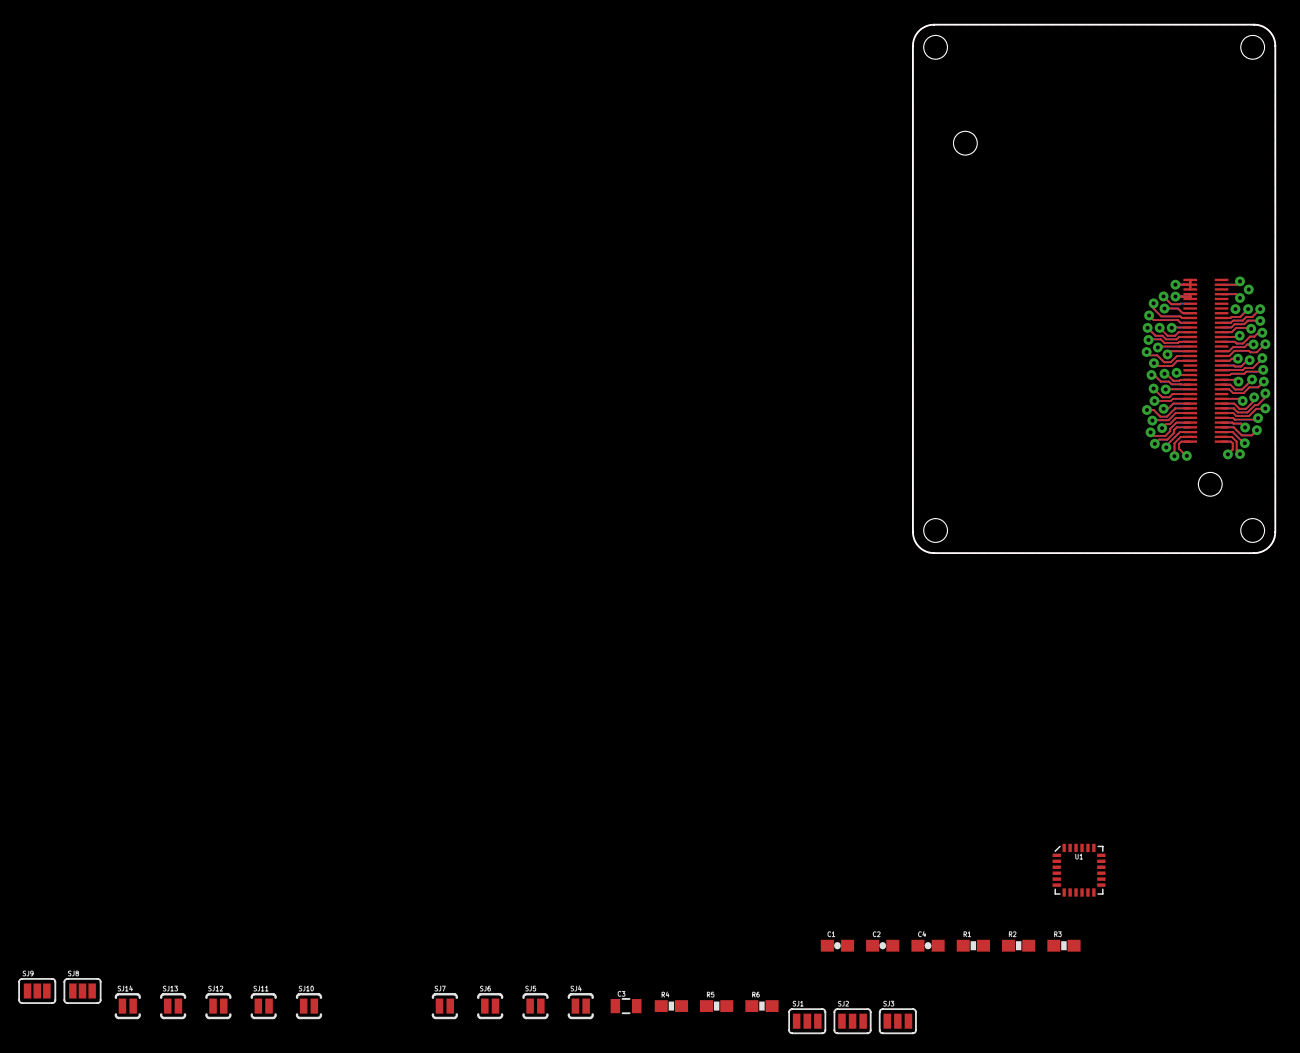
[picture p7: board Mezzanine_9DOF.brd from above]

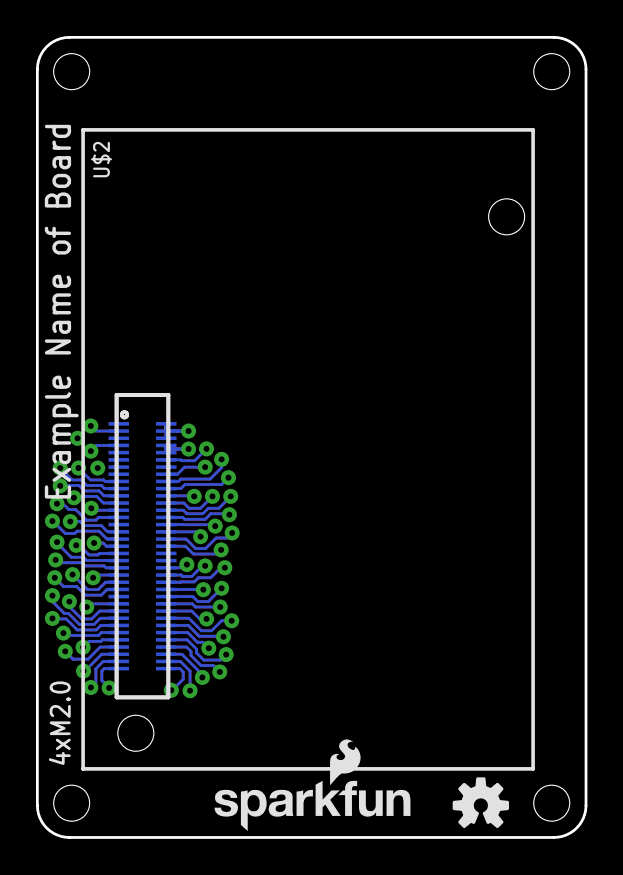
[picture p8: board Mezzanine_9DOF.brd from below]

Board: 2 copper layers, 30.5 x 44.5 mm, 31 parts (4 on the bottom side), 77 nets.

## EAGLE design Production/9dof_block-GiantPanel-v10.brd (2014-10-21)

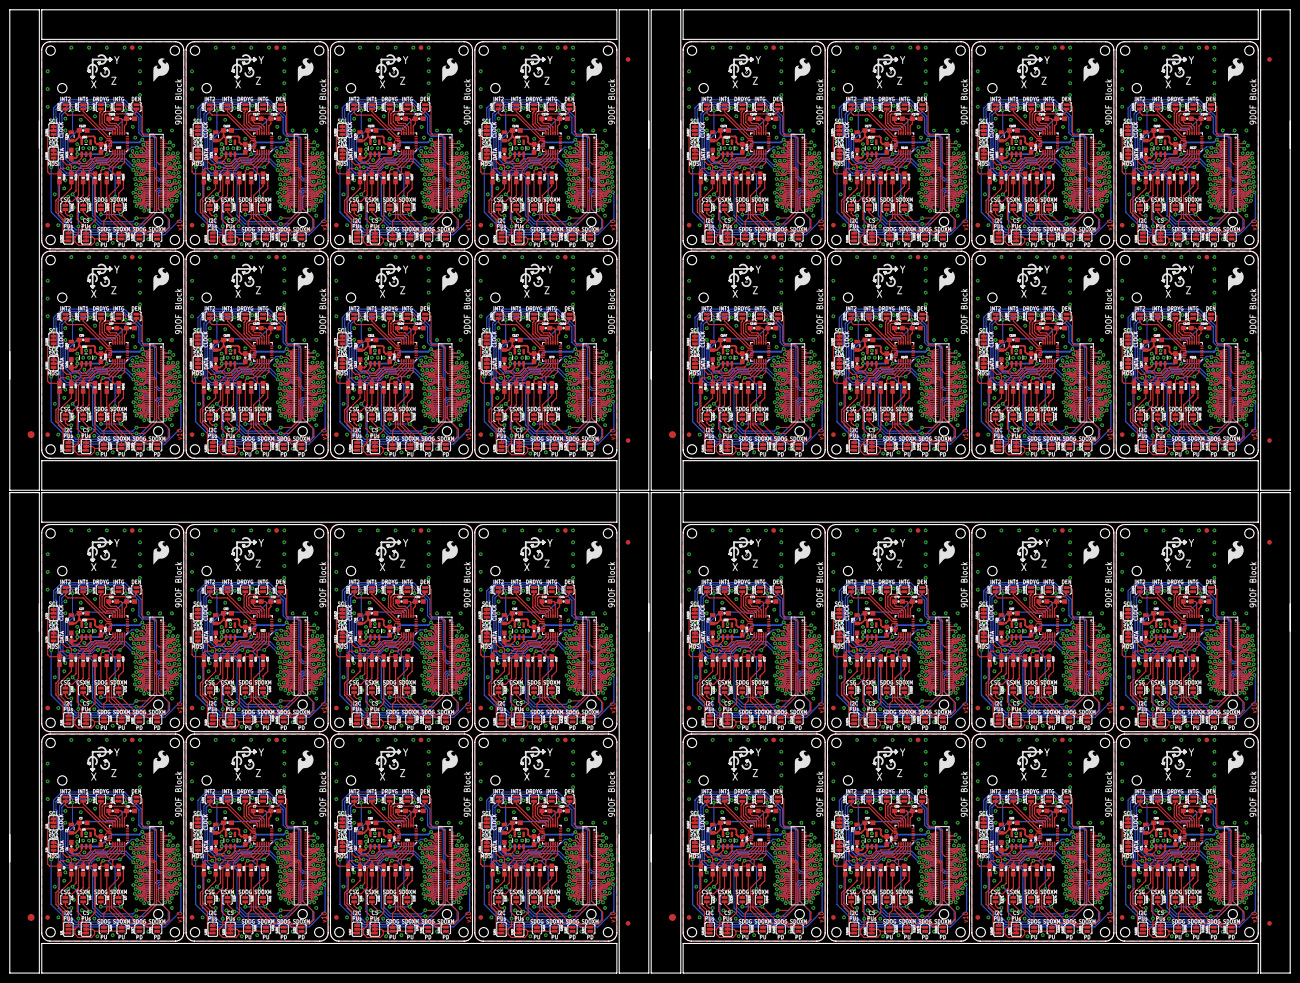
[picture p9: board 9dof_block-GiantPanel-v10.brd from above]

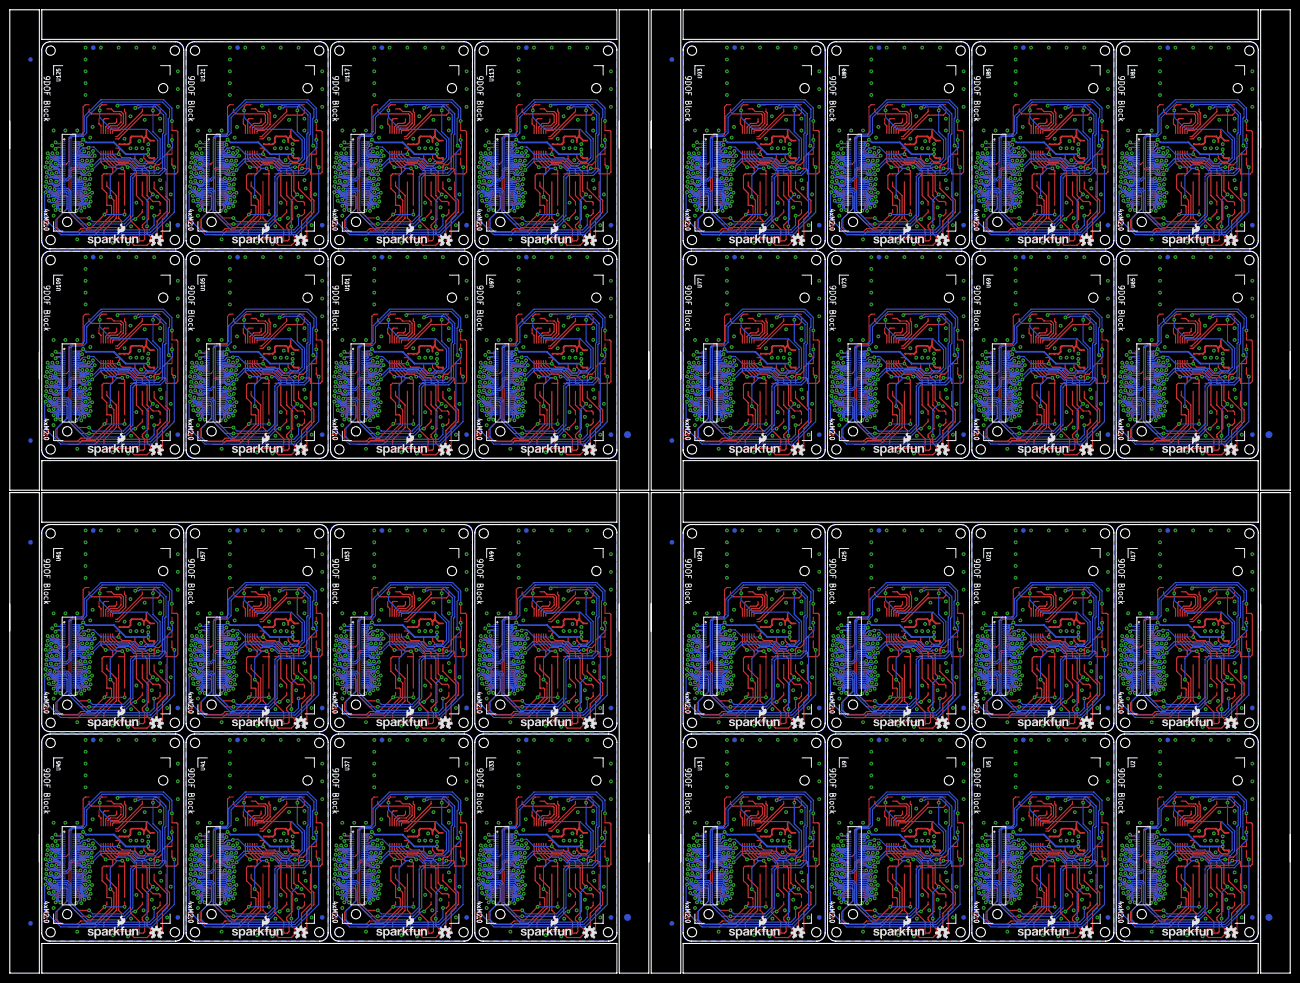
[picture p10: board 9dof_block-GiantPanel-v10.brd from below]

Board: 2 copper layers, 274.8 x 206.8 mm, 1304 parts (204 on the bottom side), 2528 nets.

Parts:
C1, C3, C9, C11, C15, C17, C21, C23, C27, C29, C33, C35, C39, C41, C45, C47, C51, C53, C57, C59, C63, C65, C69, C71, C75, C77, C81, C83, C87, C89, C93, C95, C99, C101, C105, C107, C111, C113, C117, C119, C123, C125, C129, C131, C135, C137, C141, C143, C147, C149, C153, C155, C159, C161, C165, C167, C171, C173, C177, C179, C183, C185, C189, C191: 1.0uF; 0603-CAP
C2, C10, C16, C22, C28, C34, C40, C46, C52, C58, C64, C70, C76, C82, C88, C94, C100, C106, C112, C118, C124, C130, C136, C142, C148, C154, C160, C166, C172, C178, C184, C190: 10uF; 0805
C4, C12, C18, C24, C30, C36, C42, C48, C54, C60, C66, C72, C78, C84, C90, C96, C102, C108, C114, C120, C126, C132, C138, C144, C150, C156, C162, C168, C174, C180, C186, C192: 0.1uF; 0603-CAP
C5, C7, C13, C19, C25, C31, C37, C43, C49, C55, C61, C67, C73, C79, C85, C91, C97, C103, C109, C115, C121, C127, C133, C139, C145, C151, C157, C163, C169, C175, C181, C187: 0.22uF; 0603-CAP
C6, C8, C14, C20, C26, C32, C38, C44, C50, C56, C62, C68, C74, C80, C86, C92, C98, C104, C110, C116, C122, C128, C134, C140, C146, C152, C158, C164, C170, C176, C182, C188: 4.7uF; 0603-CAP
E$1, E$2, E$9, E$10, E$15, E$16, E$21, E$22: FIDUCIAL-1.5X3
E$3, E$4, E$5, E$6, E$7, E$8, E$11, E$12, E$13, E$14, E$17, E$18, E$19, E$20, E$23, E$24: FIDUCIAL-1X2
FID1, FID2, FID3, FID4, FID5, FID6, FID7, FID8, FID9, FID10, FID11, FID12, FID13, FID14, FID15, FID16, FID17, FID18, FID19, FID20, FID21, FID22, FID23, FID24, FID25, FID26, FID27, FID28, FID29, FID30, FID31, FID32, FID33, FID34, FID35, FID36, FID37, FID38, FID39, FID40, FID41, FID42, FID43, FID44, FID45, FID46, FID47, FID48, FID49, FID50, FID51, FID52, FID53, FID54, FID55, FID56, FID57, FID58, FID59, FID60, FID61, FID62, FID63, FID64, FID65, FID66, FID67, FID68, FID69, FID70, FID71, FID72, FID73, FID74, FID75, FID76, FID77, FID78, FID79, FID80, FID81, FID82, FID83, FID84, FID85, FID86, FID87, FID88, FID89, FID90, FID91, FID92, FID93, FID94, FID95, FID96, FID97, FID98, FID99, FID100, FID101, FID102, FID103, FID104, FID105, FID106, FID107, FID108, FID109, FID110, FID111, FID112, FID113, FID114, FID115, FID116, FID117, FID118, FID119, FID120, FID121, FID122, FID123, FID124, FID125, FID126, FID127, FID128: FIDUCIAL1X2; FIDUCIAL-1X2
LOGO1, LOGO6, LOGO9, LOGO12, LOGO15, LOGO18, LOGO21, LOGO24, LOGO27, LOGO30, LOGO33, LOGO36, LOGO39, LOGO42, LOGO45, LOGO48, LOGO51, LOGO54, LOGO57, LOGO60, LOGO63, LOGO66, LOGO69, LOGO72, LOGO75, LOGO78, LOGO81, LOGO84, LOGO87, LOGO90, LOGO93, LOGO96: SFE_LOGO_FLAME.2_INCH; SFE_LOGO_FLAME_.2
LOGO2, LOGO4, LOGO7, LOGO10, LOGO13, LOGO16, LOGO19, LOGO22, LOGO25, LOGO28, LOGO31, LOGO34, LOGO37, LOGO40, LOGO43, LOGO46, LOGO49, LOGO52, LOGO55, LOGO58, LOGO61, LOGO64, LOGO67, LOGO70, LOGO73, LOGO76, LOGO79, LOGO82, LOGO85, LOGO88, LOGO91, LOGO94: OSHW-LOGOS; OSHW-LOGO-S
LOGO3, LOGO5, LOGO8, LOGO11, LOGO14, LOGO17, LOGO20, LOGO23, LOGO26, LOGO29, LOGO32, LOGO35, LOGO38, LOGO41, LOGO44, LOGO47, LOGO50, LOGO53, LOGO56, LOGO59, LOGO62, LOGO65, LOGO68, LOGO71, LOGO74, LOGO77, LOGO80, LOGO83, LOGO86, LOGO89, LOGO92, LOGO95: SFE_LOGO_NAME_FLAME.1_INCH; SFE_LOGO_NAME_FLAME_.1
R1, R2, R7, R8, R13, R14, R19, R20, R25, R26, R31, R32, R37, R38, R43, R44, R49, R50, R55, R56, R61, R62, R67, R68, R73, R74, R79, R80, R85, R86, R91, R92, R97, R98, R103, R104, R109, R110, R115, R116, R121, R122, R127, R128, R133, R134, R139, R140, R145, R146, R151, R152, R157, R158, R163, R164, R169, R170, R175, R176, R181, R182, R187, R188: 10K; 0603-RES
R3, R4, R5, R6, R9, R10, R11, R12, R15, R16, R17, R18, R21, R22, R23, R24, R27, R28, R29, R30, R33, R34, R35, R36, R39, R40, R41, R42, R45, R46, R47, R48, R51, R52, R53, R54, R57, R58, R59, R60, R63, R64, R65, R66, R69, R70, R71, R72, R75, R76, R77, R78, R81, R82, R83, R84, R87, R88, R89, R90, R93, R94, R95, R96, R99, R100, R101, R102, R105, R106, R107, R108, R111, R112, R113, R114, R117, R118, R119, R120, R123, R124, R125, R126, R129, R130, R131, R132, R135, R136, R137, R138, R141, R142, R143, R144, R147, R148, R149, R150, R153, R154, R155, R156, R159, R160, R161, R162, R165, R166, R167, R168, R171, R172, R173, R174, R177, R178, R179, R180, R183, R184, R185, R186, R189, R190, R191, R192: 10k; 0603-RES
SJ1, SJ30, SJ47, SJ64, SJ81, SJ98, SJ115, SJ132, SJ149, SJ166, SJ183, SJ200, SJ217, SJ234, SJ251, SJ268, SJ285, SJ302, SJ319, SJ336, SJ353, SJ370, SJ387, SJ404, SJ421, SJ438, SJ455, SJ472, SJ489, SJ506, SJ523, SJ540: JUMPER-PAD-3-NOYES_SILK; PAD-JUMPER-3-NO_YES_SILK
SJ2, SJ29, SJ46, SJ63, SJ80, SJ97, SJ114, SJ131, SJ148, SJ165, SJ182, SJ199, SJ216, SJ233, SJ250, SJ267, SJ284, SJ301, SJ318, SJ335, SJ352, SJ369, SJ386, SJ403, SJ420, SJ437, SJ454, SJ471, SJ488, SJ505, SJ522, SJ539: PAD-JUMPER-3-3OF3_NC_BY_TRACE_YES_SILK_FULL_BOX
SJ3, SJ15, SJ31, SJ32, SJ48, SJ49, SJ65, SJ66, SJ82, SJ83, SJ99, SJ100, SJ116, SJ117, SJ133, SJ134, SJ150, SJ151, SJ167, SJ168, SJ184, SJ185, SJ201, SJ202, SJ218, SJ219, SJ235, SJ236, SJ252, SJ253, SJ269, SJ270, SJ286, SJ287, SJ303, SJ304, SJ320, SJ321, SJ337, SJ338, SJ354, SJ355, SJ371, SJ372, SJ388, SJ389, SJ405, SJ406, SJ422, SJ423, SJ439, SJ440, SJ456, SJ457, SJ473, SJ474, SJ490, SJ491, SJ507, SJ508, SJ524, SJ525, SJ541, SJ542: JUMPER-PAD-2-NC_BY_PASTE; PAD-JUMPER-2-NC_BY_PASTE_YES_SILK
SJ4, SJ5, SJ6, SJ7, SJ10, SJ11, SJ12, SJ13, SJ14, SJ16, SJ17, SJ18, SJ19, SJ20, SJ21, SJ22, SJ23, SJ24, SJ25, SJ26, SJ33, SJ34, SJ35, SJ36, SJ37, SJ38, SJ39, SJ40, SJ41, SJ42, SJ43, SJ50, SJ51, SJ52, SJ53, SJ54, SJ55, SJ56, SJ57, SJ58, SJ59, SJ60, SJ67, SJ68, SJ69, SJ70, SJ71, SJ72, SJ73, SJ74, SJ75, SJ76, SJ77, SJ84, SJ85, SJ86, SJ87, SJ88, SJ89, SJ90, SJ91, SJ92, SJ93, SJ94, SJ101, SJ102, SJ103, SJ104, SJ105, SJ106, SJ107, SJ108, SJ109, SJ110, SJ111, SJ118, SJ119, SJ120, SJ121, SJ122, SJ123, SJ124, SJ125, SJ126, SJ127, SJ128, SJ135, SJ136, SJ137, SJ138, SJ139, SJ140, SJ141, SJ142, SJ143, SJ144, SJ145, SJ152, SJ153, SJ154, SJ155, SJ156, SJ157, SJ158, SJ159, SJ160, SJ161, SJ162, SJ169, SJ170, SJ171, SJ172, SJ173, SJ174, SJ175, SJ176, SJ177, SJ178, SJ179, SJ186, SJ187, SJ188, SJ189, SJ190, SJ191, SJ192, SJ193, SJ194, SJ195, SJ196, SJ203, SJ204, SJ205, SJ206, SJ207, SJ208, SJ209, SJ210, SJ211, SJ212, SJ213, SJ220, SJ221, SJ222, SJ223, SJ224, SJ225, SJ226, SJ227, SJ228, SJ229, SJ230, SJ237, SJ238, SJ239, SJ240, SJ241, SJ242, SJ243, SJ244, SJ245, SJ246, SJ247, SJ254, SJ255, SJ256, SJ257, SJ258, SJ259, SJ260, SJ261, SJ262, SJ263, SJ264, SJ271, SJ272, SJ273, SJ274, SJ275, SJ276, SJ277, SJ278, SJ279, SJ280, SJ281, SJ288, SJ289, SJ290, SJ291, SJ292, SJ293, SJ294, SJ295, SJ296, SJ297, SJ298, SJ305, SJ306, SJ307, SJ308, SJ309, SJ310, SJ311, SJ312, SJ313, SJ314, SJ315, SJ322, SJ323, SJ324, SJ325, SJ326, SJ327, SJ328, SJ329, SJ330, SJ331, SJ332, SJ339, SJ340, SJ341, SJ342, SJ343, SJ344, SJ345, SJ346, SJ347, SJ348, SJ349, SJ356, SJ357, SJ358, SJ359, SJ360, SJ361, SJ362, SJ363, SJ364, SJ365, SJ366, SJ373, SJ374, SJ375, SJ376, SJ377, SJ378, SJ379, SJ380, SJ381, SJ382, SJ383, SJ390, SJ391, SJ392, SJ393, SJ394, SJ395, SJ396, SJ397, SJ398, SJ399, SJ400, SJ407, SJ408, SJ409, SJ410, SJ411, SJ412, SJ413, SJ414, SJ415, SJ416, SJ417, SJ424, SJ425, SJ426, SJ427, SJ428, SJ429, SJ430, SJ431, SJ432, SJ433, SJ434, SJ441, SJ442, SJ443, SJ444, SJ445, SJ446, SJ447, SJ448, SJ449, SJ450, SJ451, SJ458, SJ459, SJ460, SJ461, SJ462, SJ463, SJ464, SJ465, SJ466, SJ467, SJ468, SJ475, SJ476, SJ477, SJ478, SJ479, SJ480, SJ481, SJ482, SJ483, SJ484, SJ485, SJ492, SJ493, SJ494, SJ495, SJ496, SJ497, SJ498, SJ499, SJ500, SJ501, SJ502, SJ509, SJ510, SJ511, SJ512, SJ513, SJ514, SJ515, SJ516, SJ517, SJ518, SJ519, SJ526, SJ527, SJ528, SJ529, SJ530, SJ531, SJ532, SJ533, SJ534, SJ535, SJ536, SJ543, SJ544: JUMPER-PAD-2-NOYES_SILK; PAD-JUMPER-2-NO_YES_SILK
SJ8, SJ9, SJ27, SJ28, SJ44, SJ45, SJ61, SJ62, SJ78, SJ79, SJ95, SJ96, SJ112, SJ113, SJ129, SJ130, SJ146, SJ147, SJ163, SJ164, SJ180, SJ181, SJ197, SJ198, SJ214, SJ215, SJ231, SJ232, SJ248, SJ249, SJ265, SJ266, SJ282, SJ283, SJ299, SJ300, SJ316, SJ317, SJ333, SJ334, SJ350, SJ351, SJ367, SJ368, SJ384, SJ385, SJ401, SJ402, SJ418, SJ419, SJ435, SJ436, SJ452, SJ453, SJ469, SJ470, SJ486, SJ487, SJ503, SJ504, SJ520, SJ521, SJ537, SJ538: JUMPER-PAD-3-2OF3_NC_BY_TRACE_SMALL; PAD-JUMPER-3-2OF3_NC_BY_TRACE_YES_SILK_FULL_BOX
U1, U7, U11, U15, U19, U23, U27, U31, U35, U39, U43, U47, U51, U55, U59, U63, U67, U71, U75, U79, U83, U87, U91, U95, U99, U103, U107, U111, U115, U119, U123, U127: LSM9DS0; LGA-24
U2, U5, U9, U13, U17, U21, U25, U29, U33, U37, U41, U45, U49, U53, U57, U61, U65, U69, U73, U77, U81, U85, U89, U93, U97, U101, U105, U109, U113, U117, U121, U125: EDISON_CONNECTOR_FULLMOUNTING_HOLES; EDISON_DAUGHTER
U3, U6, U10, U14, U18, U22, U26, U30, U34, U38, U42, U46, U50, U54, U58, U62, U66, U70, U74, U78, U82, U86, U90, U94, U98, U102, U106, U110, U114, U118, U122, U126: EDISON_CONNECTOR_FULLHEADER; DF40C-70DP-0.4(51)
U4, U8, U12, U16, U20, U24, U28, U32, U36, U40, U44, U48, U52, U56, U60, U64, U68, U72, U76, U80, U84, U88, U92, U96, U100, U104, U108, U112, U116, U120, U124, U128: MIC52053.3V; SOT23-5

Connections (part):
1.8V: SJ1.2, SJ2.2, SJ3.2, SJ15.2, U1.18, U2.12, U3.12
1.8V1: SJ29.2, SJ30.2, SJ31.2, SJ32.2, U5.12, U6.12, U7.18
1.8V2: SJ46.2, SJ47.2, SJ48.2, SJ49.2, U9.12, U10.12, U11.18
1.8V3: SJ63.2, SJ64.2, SJ65.2, SJ66.2, U13.12, U14.12, U15.18
1.8V4: SJ80.2, SJ81.2, SJ82.2, SJ83.2, U17.12, U18.12, U19.18
1.8V5: SJ97.2, SJ98.2, SJ99.2, SJ100.2, U21.12, U22.12, U23.18
1.8V6: SJ114.2, SJ115.2, SJ116.2, SJ117.2, U25.12, U26.12, U27.18
1.8V7: SJ131.2, SJ132.2, SJ133.2, SJ134.2, U29.12, U30.12, U31.18
1.8V8: SJ148.2, SJ149.2, SJ150.2, SJ151.2, U33.12, U34.12, U35.18
1.8V9: SJ165.2, SJ166.2, SJ167.2, SJ168.2, U37.12, U38.12, U39.18
1.8V10: SJ182.2, SJ183.2, SJ184.2, SJ185.2, U41.12, U42.12, U43.18
1.8V11: SJ199.2, SJ200.2, SJ201.2, SJ202.2, U45.12, U46.12, U47.18
1.8V12: SJ216.2, SJ217.2, SJ218.2, SJ219.2, U49.12, U50.12, U51.18
1.8V13: SJ233.2, SJ234.2, SJ235.2, SJ236.2, U53.12, U54.12, U55.18
1.8V14: SJ250.2, SJ251.2, SJ252.2, SJ253.2, U57.12, U58.12, U59.18
1.8V15: SJ267.2, SJ268.2, SJ269.2, SJ270.2, U61.12, U62.12, U63.18
1.8V16: SJ284.2, SJ285.2, SJ286.2, SJ287.2, U65.12, U66.12, U67.18
1.8V17: SJ301.2, SJ302.2, SJ303.2, SJ304.2, U69.12, U70.12, U71.18
1.8V18: SJ318.2, SJ319.2, SJ320.2, SJ321.2, U73.12, U74.12, U75.18
1.8V19: SJ335.2, SJ336.2, SJ337.2, SJ338.2, U77.12, U78.12, U79.18
1.8V20: SJ352.2, SJ353.2, SJ354.2, SJ355.2, U81.12, U82.12, U83.18
1.8V21: SJ369.2, SJ370.2, SJ371.2, SJ372.2, U85.12, U86.12, U87.18
1.8V22: SJ386.2, SJ387.2, SJ388.2, SJ389.2, U89.12, U90.12, U91.18
1.8V23: SJ403.2, SJ404.2, SJ405.2, SJ406.2, U93.12, U94.12, U95.18
1.8V24: SJ420.2, SJ421.2, SJ422.2, SJ423.2, U97.12, U98.12, U99.18
1.8V25: SJ437.2, SJ438.2, SJ439.2, SJ440.2, U101.12, U102.12, U103.18
1.8V26: SJ454.2, SJ455.2, SJ456.2, SJ457.2, U105.12, U106.12, U107.18
1.8V27: SJ471.2, SJ472.2, SJ473.2, SJ474.2, U109.12, U110.12, U111.18
1.8V28: SJ488.2, SJ489.2, SJ490.2, SJ491.2, U113.12, U114.12, U115.18
1.8V29: SJ505.2, SJ506.2, SJ507.2, SJ508.2, U117.12, U118.12, U119.18
1.8V30: SJ522.2, SJ523.2, SJ524.2, SJ525.2, U121.12, U122.12, U123.18
1.8V31: SJ539.2, SJ540.2, SJ541.2, SJ542.2, U125.12, U126.12, U127.18
3.3V: U2.8, U2.10, U3.8, U3.10
3.3V1: U5.8, U5.10, U6.8, U6.10
3.3V2: U9.8, U9.10, U10.8, U10.10
3.3V3: U13.8, U13.10, U14.8, U14.10
3.3V4: U17.8, U17.10, U18.8, U18.10
3.3V5: U21.8, U21.10, U22.8, U22.10
3.3V6: U25.8, U25.10, U26.8, U26.10
3.3V7: U29.8, U29.10, U30.8, U30.10
3.3V8: U33.8, U33.10, U34.8, U34.10
3.3V9: U37.8, U37.10, U38.8, U38.10
3.3V10: U41.8, U41.10, U42.8, U42.10
3.3V11: U45.8, U45.10, U46.8, U46.10
3.3V12: U49.8, U49.10, U50.8, U50.10
3.3V13: U53.8, U53.10, U54.8, U54.10
3.3V14: U57.8, U57.10, U58.8, U58.10
3.3V15: U61.8, U61.10, U62.8, U62.10
3.3V16: U65.8, U65.10, U66.8, U66.10
3.3V17: U69.8, U69.10, U70.8, U70.10
3.3V18: U73.8, U73.10, U74.8, U74.10
3.3V19: U77.8, U77.10, U78.8, U78.10
3.3V20: U81.8, U81.10, U82.8, U82.10
3.3V21: U85.8, U85.10, U86.8, U86.10
3.3V22: U89.8, U89.10, U90.8, U90.10
3.3V23: U93.8, U93.10, U94.8, U94.10
3.3V24: U97.8, U97.10, U98.8, U98.10
3.3V25: U101.8, U101.10, U102.8, U102.10
3.3V26: U105.8, U105.10, U106.8, U106.10
3.3V27: U109.8, U109.10, U110.8, U110.10
3.3V28: U113.8, U113.10, U114.8, U114.10
3.3V29: U117.8, U117.10, U118.8, U118.10
3.3V30: U121.8, U121.10, U122.8, U122.10
3.3V31: U125.8, U125.10, U126.8, U126.10
3.3V_LOCAL: C2.1, C3.1, C4.1, U1.15, U1.16, U1.17, U4.5
3.3V_LOCAL1: C9.1, C10.1, C12.1, U7.15, U7.16, U7.17, U8.5
3.3V_LOCAL2: C15.1, C16.1, C18.1, U11.15, U11.16, U11.17, U12.5
3.3V_LOCAL3: C21.1, C22.1, C24.1, U15.15, U15.16, U15.17, U16.5
3.3V_LOCAL4: C27.1, C28.1, C30.1, U19.15, U19.16, U19.17, U20.5
3.3V_LOCAL5: C33.1, C34.1, C36.1, U23.15, U23.16, U23.17, U24.5
3.3V_LOCAL6: C39.1, C40.1, C42.1, U27.15, U27.16, U27.17, U28.5
3.3V_LOCAL7: C45.1, C46.1, C48.1, U31.15, U31.16, U31.17, U32.5
3.3V_LOCAL8: C51.1, C52.1, C54.1, U35.15, U35.16, U35.17, U36.5
3.3V_LOCAL9: C57.1, C58.1, C60.1, U39.15, U39.16, U39.17, U40.5
3.3V_LOCAL10: C63.1, C64.1, C66.1, U43.15, U43.16, U43.17, U44.5
3.3V_LOCAL11: C69.1, C70.1, C72.1, U47.15, U47.16, U47.17, U48.5
3.3V_LOCAL12: C75.1, C76.1, C78.1, U51.15, U51.16, U51.17, U52.5
3.3V_LOCAL13: C81.1, C82.1, C84.1, U55.15, U55.16, U55.17, U56.5
3.3V_LOCAL14: C87.1, C88.1, C90.1, U59.15, U59.16, U59.17, U60.5
3.3V_LOCAL15: C93.1, C94.1, C96.1, U63.15, U63.16, U63.17, U64.5
3.3V_LOCAL16: C99.1, C100.1, C102.1, U67.15, U67.16, U67.17, U68.5
3.3V_LOCAL17: C105.1, C106.1, C108.1, U71.15, U71.16, U71.17, U72.5
3.3V_LOCAL18: C111.1, C112.1, C114.1, U75.15, U75.16, U75.17, U76.5
3.3V_LOCAL19: C117.1, C118.1, C120.1, U79.15, U79.16, U79.17, U80.5
3.3V_LOCAL20: C123.1, C124.1, C126.1, U83.15, U83.16, U83.17, U84.5
3.3V_LOCAL21: C129.1, C130.1, C132.1, U87.15, U87.16, U87.17, U88.5
3.3V_LOCAL22: C135.1, C136.1, C138.1, U91.15, U91.16, U91.17, U92.5
3.3V_LOCAL23: C141.1, C142.1, C144.1, U95.15, U95.16, U95.17, U96.5
3.3V_LOCAL24: C147.1, C148.1, C150.1, U99.15, U99.16, U99.17, U100.5
3.3V_LOCAL25: C153.1, C154.1, C156.1, U103.15, U103.16, U103.17, U104.5
3.3V_LOCAL26: C159.1, C160.1, C162.1, U107.15, U107.16, U107.17, U108.5
3.3V_LOCAL27: C165.1, C166.1, C168.1, U111.15, U111.16, U111.17, U112.5
3.3V_LOCAL28: C171.1, C172.1, C174.1, U115.15, U115.16, U115.17, U116.5
3.3V_LOCAL29: C177.1, C178.1, C180.1, U119.15, U119.16, U119.17, U120.5
3.3V_LOCAL30: C183.1, C184.1, C186.1, U123.15, U123.16, U123.17, U124.5
3.3V_LOCAL31: C189.1, C190.1, C192.1, U127.15, U127.16, U127.17, U128.5
CS_G: R3.1, SJ4.1, U1.19
CS_G1: R9.1, SJ18.1, U7.19
CS_G2: R15.1, SJ35.1, U11.19
CS_G3: R21.1, SJ52.1, U15.19
CS_G4: R27.1, SJ69.1, U19.19
CS_G5: R33.1, SJ86.1, U23.19
CS_G6: R39.1, SJ103.1, U27.19
CS_G7: R45.1, SJ120.1, U31.19
CS_G8: R51.1, SJ137.1, U35.19
CS_G9: R57.1, SJ154.1, U39.19
CS_G10: R63.1, SJ171.1, U43.19
CS_G11: R69.1, SJ188.1, U47.19
CS_G12: R75.1, SJ205.1, U51.19
CS_G13: R81.1, SJ222.1, U55.19
CS_G14: R87.1, SJ239.1, U59.19
CS_G15: R93.1, SJ256.1, U63.19
CS_G16: R99.1, SJ273.1, U67.19
CS_G17: R105.1, SJ290.1, U71.19
CS_G18: R111.1, SJ307.1, U75.19
CS_G19: R117.1, SJ324.1, U79.19
CS_G20: R123.1, SJ341.1, U83.19
CS_G21: R129.1, SJ358.1, U87.19
CS_G22: R135.1, SJ375.1, U91.19
CS_G23: R141.1, SJ392.1, U95.19
CS_G24: R147.1, SJ409.1, U99.19
CS_G25: R153.1, SJ426.1, U103.19
CS_G26: R159.1, SJ443.1, U107.19
CS_G27: R165.1, SJ460.1, U111.19
CS_G28: R171.1, SJ477.1, U115.19
CS_G29: R177.1, SJ494.1, U119.19
CS_G30: R183.1, SJ511.1, U123.19
CS_G31: R189.1, SJ528.1, U127.19
CS_XM: R4.1, SJ5.1, U1.20
CS_XM1: R10.1, SJ19.1, U7.20
CS_XM2: R16.1, SJ36.1, U11.20
CS_XM3: R22.1, SJ53.1, U15.20
CS_XM4: R28.1, SJ70.1, U19.20
CS_XM5: R34.1, SJ87.1, U23.20
CS_XM6: R40.1, SJ104.1, U27.20
CS_XM7: R46.1, SJ121.1, U31.20
CS_XM8: R52.1, SJ138.1, U35.20
CS_XM9: R58.1, SJ155.1, U39.20
CS_XM10: R64.1, SJ172.1, U43.20
CS_XM11: R70.1, SJ189.1, U47.20
CS_XM12: R76.1, SJ206.1, U51.20
CS_XM13: R82.1, SJ223.1, U55.20
CS_XM14: R88.1, SJ240.1, U59.20
CS_XM15: R94.1, SJ257.1, U63.20
CS_XM16: R100.1, SJ274.1, U67.20
CS_XM17: R106.1, SJ291.1, U71.20
CS_XM18: R112.1, SJ308.1, U75.20
CS_XM19: R118.1, SJ325.1, U79.20
CS_XM20: R124.1, SJ342.1, U83.20
CS_XM21: R130.1, SJ359.1, U87.20
CS_XM22: R136.1, SJ376.1, U91.20
CS_XM23: R142.1, SJ393.1, U95.20
CS_XM24: R148.1, SJ410.1, U99.20
CS_XM25: R154.1, SJ427.1, U103.20
CS_XM26: R160.1, SJ444.1, U107.20
CS_XM27: R166.1, SJ461.1, U111.20
CS_XM28: R172.1, SJ478.1, U115.20
CS_XM29: R178.1, SJ495.1, U119.20
CS_XM30: R184.1, SJ512.1, U123.20
CS_XM31: R190.1, SJ529.1, U127.20
DCIN: U2.14, U3.14
DCIN1: U5.14, U6.14
DCIN2: U9.14, U10.14
DCIN3: U13.14, U14.14
DCIN4: U17.14, U18.14
DCIN5: U21.14, U22.14
DCIN6: U25.14, U26.14
DCIN7: U29.14, U30.14
DCIN8: U33.14, U34.14
DCIN9: U37.14, U38.14
DCIN10: U41.14, U42.14
DCIN11: U45.14, U46.14
DCIN12: U49.14, U50.14
DCIN13: U53.14, U54.14
DCIN14: U57.14, U58.14
DCIN15: U61.14, U62.14
DCIN16: U65.14, U66.14
DCIN17: U69.14, U70.14
DCIN18: U73.14, U74.14
DCIN19: U77.14, U78.14
DCIN20: U81.14, U82.14
DCIN21: U85.14, U86.14
DCIN22: U89.14, U90.14
DCIN23: U93.14, U94.14
DCIN24: U97.14, U98.14
DCIN25: U101.14, U102.14
DCIN26: U105.14, U106.14
DCIN27: U109.14, U110.14
DCIN28: U113.14, U114.14
DCIN29: U117.14, U118.14
DCIN30: U121.14, U122.14
DCIN31: U125.14, U126.14
DEN_G: SJ10.1, U1.10
DEN_G1: SJ22.1, U7.10
DEN_G2: SJ39.1, U11.10
DEN_G3: SJ56.1, U15.10
DEN_G4: SJ73.1, U19.10
DEN_G5: SJ90.1, U23.10
DEN_G6: SJ107.1, U27.10
DEN_G7: SJ124.1, U31.10
DEN_G8: SJ141.1, U35.10
DEN_G9: SJ158.1, U39.10
DEN_G10: SJ175.1, U43.10
DEN_G11: SJ192.1, U47.10
DEN_G12: SJ209.1, U51.10
DEN_G13: SJ226.1, U55.10
DEN_G14: SJ243.1, U59.10
DEN_G15: SJ260.1, U63.10
DEN_G16: SJ277.1, U67.10
DEN_G17: SJ294.1, U71.10
DEN_G18: SJ311.1, U75.10
DEN_G19: SJ328.1, U79.10
DEN_G20: SJ345.1, U83.10
DEN_G21: SJ362.1, U87.10
DEN_G22: SJ379.1, U91.10
DEN_G23: SJ396.1, U95.10
DEN_G24: SJ413.1, U99.10
DEN_G25: SJ430.1, U103.10
DEN_G26: SJ447.1, U107.10
DEN_G27: SJ464.1, U111.10
DEN_G28: SJ481.1, U115.10
DEN_G29: SJ498.1, U119.10
DEN_G30: SJ515.1, U123.10
DEN_G31: SJ532.1, U127.10
DRDY_G: SJ12.1, U1.12
DRDY_G1: SJ24.1, U7.12
DRDY_G2: SJ41.1, U11.12
DRDY_G3: SJ58.1, U15.12
DRDY_G4: SJ75.1, U19.12
DRDY_G5: SJ92.1, U23.12
DRDY_G6: SJ109.1, U27.12
DRDY_G7: SJ126.1, U31.12
DRDY_G8: SJ143.1, U35.12
DRDY_G9: SJ160.1, U39.12
DRDY_G10: SJ177.1, U43.12
DRDY_G11: SJ194.1, U47.12
DRDY_G12: SJ211.1, U51.12
DRDY_G13: SJ228.1, U55.12
DRDY_G14: SJ245.1, U59.12
DRDY_G15: SJ262.1, U63.12
DRDY_G16: SJ279.1, U67.12
DRDY_G17: SJ296.1, U71.12
DRDY_G18: SJ313.1, U75.12
DRDY_G19: SJ330.1, U79.12
DRDY_G20: SJ347.1, U83.12
DRDY_G21: SJ364.1, U87.12
DRDY_G22: SJ381.1, U91.12
DRDY_G23: SJ398.1, U95.12
DRDY_G24: SJ415.1, U99.12
DRDY_G25: SJ432.1, U103.12
DRDY_G26: SJ449.1, U107.12
DRDY_G27: SJ466.1, U111.12
DRDY_G28: SJ483.1, U115.12
DRDY_G29: SJ500.1, U119.12
DRDY_G30: SJ517.1, U123.12
DRDY_G31: SJ534.1, U127.12
FAULT: U2.19, U3.19
FAULT1: U5.19, U6.19
FAULT2: U9.19, U10.19
FAULT3: U13.19, U14.19
FAULT4: U17.19, U18.19
FAULT5: U21.19, U22.19
FAULT6: U25.19, U26.19
FAULT7: U29.19, U30.19
FAULT8: U33.19, U34.19
FAULT9: U37.19, U38.19
FAULT10: U41.19, U42.19
FAULT11: U45.19, U46.19
FAULT12: U49.19, U50.19
FAULT13: U53.19, U54.19
FAULT14: U57.19, U58.19
FAULT15: U61.19, U62.19
FAULT16: U65.19, U66.19
FAULT17: U69.19, U70.19
FAULT18: U73.19, U74.19
FAULT19: U77.19, U78.19
FAULT20: U81.19, U82.19
FAULT21: U85.19, U86.19
FAULT22: U89.19, U90.19
FAULT23: U93.19, U94.19
FAULT24: U97.19, U98.19
FAULT25: U101.19, U102.19
FAULT26: U105.19, U106.19
FAULT27: U109.19, U110.19
FAULT28: U113.19, U114.19
FAULT29: U117.19, U118.19
FAULT30: U121.19, U122.19
FAULT31: U125.19, U126.19
FW_RCVR: U2.69, U3.69
FW_RCVR1: U5.69, U6.69
FW_RCVR2: U9.69, U10.69
FW_RCVR3: U13.69, U14.69
FW_RCVR4: U17.69, U18.69
FW_RCVR5: U21.69, U22.69
FW_RCVR6: U25.69, U26.69
FW_RCVR7: U29.69, U30.69
FW_RCVR8: U33.69, U34.69
FW_RCVR9: U37.69, U38.69
FW_RCVR10: U41.69, U42.69
FW_RCVR11: U45.69, U46.69
FW_RCVR12: U49.69, U50.69
FW_RCVR13: U53.69, U54.69
FW_RCVR14: U57.69, U58.69
FW_RCVR15: U61.69, U62.69
FW_RCVR16: U65.69, U66.69
FW_RCVR17: U69.69, U70.69
FW_RCVR18: U73.69, U74.69
FW_RCVR19: U77.69, U78.69
FW_RCVR20: U81.69, U82.69
FW_RCVR21: U85.69, U86.69
FW_RCVR22: U89.69, U90.69
FW_RCVR23: U93.69, U94.69
FW_RCVR24: U97.69, U98.69
FW_RCVR25: U101.69, U102.69
FW_RCVR26: U105.69, U106.69
FW_RCVR27: U109.69, U110.69
FW_RCVR28: U113.69, U114.69
FW_RCVR29: U117.69, U118.69
FW_RCVR30: U121.69, U122.69
FW_RCVR31: U125.69, U126.69
GND: C1.2, C2.2, C3.2, C4.2, C6.2, SJ16.1, SJ17.1, U1.2, U1.3, U1.4, U1.5, U1.6, U2.1, U2.5, U2.9, U2.11, U2.13, U2.15, U3.1, U3.5, U3.9, U3.11, U3.13, U3.15, U4.2
GND1: C8.2, C9.2, C10.2, C11.2, C12.2, SJ33.1, SJ34.1, U5.1, U5.5, U5.9, U5.11, U5.13, U5.15, U6.1, U6.5, U6.9, U6.11, U6.13, U6.15, U7.2, U7.3, U7.4, U7.5, U7.6, U8.2
GND2: C14.2, C15.2, C16.2, C17.2, C18.2, SJ50.1, SJ51.1, U9.1, U9.5, U9.9, U9.11, U9.13, U9.15, U10.1, U10.5, U10.9, U10.11, U10.13, U10.15, U11.2, U11.3, U11.4, U11.5, U11.6, U12.2
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

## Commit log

2014-08-06 Created initial schematic
    [Mezzanine_9DOF.brd, Mezzanine_9DOF.sch]
2014-08-07 Updated to new template. Initial component placement.
    [edison_mezzanine_9dof.brd, edison_mezzanine_9dof.sch]
2014-08-07 v01 board layout complete
    [edison_mezzanine_9dof.brd, edison_mezzanine_9dof.sch]
2014-08-08 Added LDO
    [edison_mezzanine_9dof.brd, edison_mezzanine_9dof.sch]
2014-08-08 Changed to 1.8V IO and added 4x 2-way jumpers for address select.
    [edison_mezzanine_9dof.brd, edison_mezzanine_9dof.sch]
2014-08-09 Re-did power section to include LDO. Added 4x 2-way jumpers to layout for pullups/pulldowns.
    [edison_mezzanine_9dof.brd, edison_mezzanine_9dof.sch]
2014-08-09 Added fiducials and moved ver text on layout. Moved address table near pullups/pulldowns on schematic.
    [edison_mezzanine_9dof.brd, edison_mezzanine_9dof.sch]
2014-08-09 Added second side fiducials.
    [edison_mezzanine_9dof.brd, edison_mezzanine_9dof.sch]
2014-08-11 Connected SDO_XM and SDO_G together to SPI2_RX on Edison.
    [edison_mezzanine_9dof.brd, edison_mezzanine_9dof.sch]
2014-08-11 Fixed hanging wire from LDO and added LDO chip name to schematic.
    [edison_mezzanine_9dof.brd, edison_mezzanine_9dof.sch]
2014-08-12 Changed silk name from Edzzanine 9DOF to just 9DOF.
    [edison_mezzanine_9dof.brd]
2014-09-24 Added DCIN pin Corrected Header footprint Modified Name of board cleaned up units and added units cleaned up copper fills
    [edison_mezzanine_9dof.brd, edison_mezzanine_9dof.sch]
2014-10-16 Rev to 10, fix gnd and pwr, text
    [edison_mezzanine_9dof.brd, edison_mezzanine_9dof.sch]
2014-10-17 Paste to trace jumpers, edit packages
    [edison_mezzanine_9dof.brd, edison_mezzanine_9dof.sch]
2014-10-17 Rename files
    [9dof_block.brd, 9dof_block.sch]
2014-10-17 Ready for reds, v10
    [9dof_block.brd]
2014-10-21 moved fid
    [9dof_block-Panel-v10.brd]
2014-10-21 created v10 panels
    [9dof_block-GiantPanel-v10.brd, 9dof_block-Panel-v10.brd]
2016-01-20 Update directory name
    [9dof_block-GiantPanel-v10.brd, 9dof_block-Panel-v10.brd]

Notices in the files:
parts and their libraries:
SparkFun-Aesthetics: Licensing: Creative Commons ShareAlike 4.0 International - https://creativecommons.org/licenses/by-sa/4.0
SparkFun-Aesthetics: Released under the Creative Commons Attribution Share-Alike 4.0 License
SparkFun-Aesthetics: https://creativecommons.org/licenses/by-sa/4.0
